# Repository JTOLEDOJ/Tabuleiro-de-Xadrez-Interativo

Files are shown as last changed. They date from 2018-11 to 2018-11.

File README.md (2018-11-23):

# TCIC

Nome do projeto: "Implementação de um sistema eletromecânico para auxílio de novos jogadores de xadrez utilizando a plataforma Arduino"

Autores:
* Álvaro Carvalho Vieira
* Erick de Barros Alcântara
* Igor Lima Rodrigues Pereira
* José Antonio Toledo Júnior

Universidade: UFSJ-CAP

Curso: Engenharia Mecatrônica

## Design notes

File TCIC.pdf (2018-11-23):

Universidade Federal de São João del-Rei

Campus Alto Paraopeba

## TRABALHO DE CONTEXTUALIZAÇÃO E INTEGRAÇÃO

## CURRICULAR – TCIC

“Implementação de um sistema eletromecânico para auxílio de novos

jogadores de xadrez utilizando a plataforma Arduino”

Álvaro Carvalho Vieira

Erick de Barros Alcântara

Igor Lima Rodrigues Pereira

José Antonio Toledo Júnior

Ouro Branco, MG

Julho de 2018

UNIVERSIDADE FEDERAL DE SÃO JOÃO DEL-REI

INSTITUIDA PELA LEI Nº. 10.425 DE 19/04/2002 – D.O.U DE 22/04/2002 CAMPUS ALTO PARAOPEBA
ENGENHARIA MECATRÔNICA

Álvaro Carvalho Vieira

Erick de Barros Alcântara

Igor Lima Rodrigues Pereira

José Antonio Toledo Júnior

“IMPLEMENTAÇÃO DE UM SISTEMA ELETROMECÂNICO PARA

AUXÍLO DE NOVOS JOGADORES DE XADREZ UTILIZANDO A

PLATAFORMA ARDUINO”

Trabalho apresentado ao Bacharelado

Interdisciplinar em Ciência e Tecnologia da

Universidade Federal de São João del-Rei

(UFSJ), como requisito essencial para

obtenção do grau de Bacharel, sob a

orientação do Prof. Dr. Guilherme Gomes

da Silva.

Ouro Branco, MG

Julho de 2018

AGRADECIMENTOS

É muito bom passar por uma jornada dessas, ter tanto a agradecer e querer

homenagear tantas pessoas. É muito valioso dizer obrigado a todos aqueles que,

durante este período, em que foi despertado sentimento de tristeza, incapacidade,

euforia, incerteza, cansaço, alegrias, conseguiram manter-se inevitavelmente

presentes. Por isso, as homenagens:

A Deus, Aquele que se apresentou e se apresenta nas mais variadas formas,

sendo este o motivo de continuar a tentar e almejar a conclusão de nossos sonhos,

dando-nos força para finalizar este projeto.

Em especial aos nossos pais, a quem devemos a vida, a formação moral e a

criação de nossa identidade. Nosso reconhecimento e gratidão por toda a paciência,

amor, compreensão e apoio constante.

Aos professores, os parabenizamos pelo compromisso e dedicação. Nossos

eternos agradecimentos pelas inúmeras contribuições.

Aos nossos queridos colegas e amigos, pelos momentos de convívio, risos,

trocas de conhecimentos, afetos e intrigas, e que por meio delas, amadurecemos.

RESUMO

O presente trabalho objetiva a elaboração de um tabuleiro de xadrez que auxilie

novos jogadores a aprenderem de forma interativa a jogar tal jogo. Para atingir a

finalidade proposta, foi utilizado software de simulação mecânica, plataforma Arduino,

fundamentos teóricos de programação, circuitos elétricos e eletrônica, além das leis

que regem o jogo. No desenvolver deste projeto, foi mostrado como hardware e

software, além da estrutura mecânica, foram elaborados para funcionarem em

conjunto, obtendo o resultado esperado do protótipo construído para facilitar

jogadores novatos de xadrez.

Palavras Chave: Projeto, Xadrez, Arduino.

ABSTRACT

The present work aims at the elaboration of a chessboard that helps new players

to learn the interactive way of playing the game. For the proposed adaptation, it was

used the software of accumulated mechanics, Arduino platform, theoretical

fundamentals of programming, electrical and electric, besides the laws that govern the

game. In the build this design, it was exposed how hardware and software, in addition

to the mechanical structure, were designed to work together, getting the expected

result of the prototype to be improved in novices of chess.

Keywords: Project, Chess, Arduino.

LISTA DE ILUSTRAÇÕES

LISTA DE SIGLAS

1. IMSA – Associação Internacional de Esportes Mentais | 11
2. FIDE – Federação Internacional de Xadrez | 13
3. USB – Universal Serial Bus | 18
4. PC – Personal Computer | 18
5. DC – Direct Current | 19
6. IOREF – Input/Output Reference | 20
7. GND – Ground | 20
8. VIN – Voltage Input | 21
9. CDC – Communication Device Class | 21
10.RISC – Reduced Instruction Set Computer | 21
11.TQFP – Quad Flat Package | 21
12.SMD – Surface Mount Tecnology | 21
13.SRAM – Static Random Access Memory | 21

14.EEPROM – Electrically-Erasable Programmable Read-Only Memory .........21

15.PWM – Pulse-Width Modulation | 22
16.RX – Data Reciver | 22
17.TX – Data Transmiter | 22
18.I2C – Inter-Integrated Circuit | 22
19.SDA – Serial Data | 22
20.SCL – Serial Clock | 22
21.SPI – Serial Peripheral Interface | 23
22.ICSP – In-circuit serial programming | 23
23.AD – Analog-to-Digital | 23
24.AD – Analog Reference | 23
25.LED – Light Emitting Diode | 23
26.DEMUX – Demultiplexer | 25
27.MUX – Multiplexer | 26
28.PCB – Printed Circuit Board | 27
29.CNC – Computer Numeric Control | 33
30.CD/DVD – Compact Disc / Digital Versatile Disc | 42

SUMÁRIO

### 1. INTRODUÇÃO

Ao contextualizar o termo automação, tem-se como foco e visão um sistema

automático de controle pelo qual os mecanismos verificam seu próprio funcionamento,

efetuando medições e introduzindo correções, sem a necessidade da interferência do

homem [1].

Em seu uso moderno, a automação pode ser definida como uma tecnologia que

utiliza comandos programados para operar um dado processo, combinados com

retroação de informação para determinar que os comandos sejam executados

corretamente. Frequentemente utilizada em processos antes operados por seres

humanos, é a aplicação de técnicas computadorizadas ou mecânicas para diminuir o

uso de mão-de-obra em qualquer processo [2].

Ao ingressar no curso de Engenharia Mecatrônica na Universidade Federal de

São João del-Rei - Campus Alto Paraopeba (UFSJ-CAP), são apresentados ao aluno

conhecimentos na área da automação, controle, eletrônica, programação e mecânica

durante aulas, palestras, seminários, viagens técnicas, feiras e outras atividades

complementares que possibilitam a formação de uma pessoa dinâmica, criativa, lógica

e resiliente.

Por meio deste processo o aluno está capacitado a procurar oportunidades de

projetos, conceber a ideia e desenvolvê-las por meio de uma Iniciação Científica, TCC,

TCIC ou Programa de Extensão. Tudo isso é estruturado por uma extensa pesquisa,

parte primordial para a implementação de qualquer projeto.

A popularização dos microcontroladores junto com a queda dos custos de

componentes eletrônicos, baterias e motores, possibilitaram o desenvolvimento de

pequenas plataformas autônomas de baixo custo [3].

A implementação de uma plataforma automática envolve conceitos de

eletrônica, computação e mecânica que, integrados de forma sincronizada,

possibilitam a construção de um sistema embarcado. Para realizar essa integração é

utilizado um microcontrolador que gerenciam os periféricos a ele conectados. Através

de embasamentos teóricos, ocorre a ideia de criar um “xadrez interativo”, com o objetivo de auxiliar novos jogadores no processo de aprendizado sobre o jogo,

tornando mais intuitivo e ágil esse processo.

### 2. REFERENCIAL TEÓRICO

### 2.1 Xadrez

O jogo de xadrez, integrado como esporte mental pela Associação Internacional

de Esportes Mentais (IMSA) desde 2005, é reconhecido por desenvolver as

capacidades de cognição como memória, tomada de decisão, raciocínio lógico-

matemático e inteligência espacial.

Segundo o papa Inocêncio III (papa entre 1198 e 1216) [4]:

Este mundo todo é como um tabuleiro de xadrez: uma casa é branca, outra casa é preta, e assim representa o duplo estado de vida ou de morte, de graça ou pecado. A família que habita esse tabuleiro é formada pelos homens deste mundo, que – tal como as peças saídas todas da mesma bolsa – procedem todos de um só ventre materno. E, tal como as peças, assumem seus postos nos diferentes lugares deste mundo, cada um com sua própria denominação. O primeiro é o Rei, depois a Rainha, em terceiro lugar a Torre, em quarto o Cavalo, em quinto o Bispo e em sexto o Peão. E o caráter do jogo é tal que um toma o outro e, com o jogo terminado, assim como todos tinham saído da mesma bolsa, a ela voltam. E então já não há diferença entre o Rei e o pobre Peão, pois acabam do mesmo modo o rico e o pobre. E com frequência acontece que, quando se devolvem as peças, o Rei fica por baixo, no fundo do saco; e assim também acontece com os grandes que ao sair deste mundo são sepultados no inferno; enquanto os pobres são levados ao seio de Abraão.

A referência [5] traz as informações a seguir, sendo que para eles o xadrez

apresenta-se como uma rica ferramenta no processo de tomada de decisões para os

diversos fatores de nossa vida. Diferentemente de outros esportes-jogos, como no

futebol onde o centroavante desperdiça vários chutes à gol – concluindo muitas vezes

apenas uma tentativa entre tantas – o xadrez com toda a sua precisão não permite

este “luxo”, pois qualquer que seja pequeno o erro de cálculo ou má visualização da

tomada de decisão, pode acarretar em uma derrota imediata, assim:

“As decisões são escolhas tomadas com base em propósitos, são ações

orientadas para determinado objetivo e o alcance deste objetivo determina a eficiência

do processo de tomada de decisão” (SHENK, 2006).

Xadrez é claramente um "caminho ideal para o estudo de tomada de decisão e

resolução de problemas, porque é um sistema fechado, com regras claramente

definidas" (Horgan, 1988).

Quando confrontados com um problema, o primeiro passo é "analisar [o] de

uma forma preliminar e impressionista: avaliando o problema" (Horgan, 1988, p. 3),

possivelmente à procura de padrões ou semelhança com experiências anteriores.

"Juízos de similaridade pode envolver altos níveis de raciocínio abstrato" (Horgan,

1988, p. 3). Como o estudo de padrões na matemática, o reconhecimento de padrões

em xadrez é de primordial importância na resolução de problemas. Depois de

reconhecer a semelhança de padrões, uma estratégia global pode ser desenvolvida

para resolver o problema. Trata-se de alternativas de produção, um processo criativo.

Um bom jogador de xadrez, como um solucionador de problemas bom, tem

"adquirido um vasto número de esquemas inter-relacionados" (Horgan, 1988, p. 3),

permitindo uma boa alternativa para rápida e fácil resolução vêm à mente. Essas

alternativas devem ser avaliadas, através de um processo de cálculo conhecido como

análise da árvore de decisão, onde solver o jogador de xadrez / problema é calcular a

conveniência de eventos futuros com base nas alternativas estão sendo analisadas.

Horgan (1988) constatou que "o cálculo pode ir várias jogadas a oito ou dez

anos à frente. Esta fase exige concentração grave e habilidades de memória ... [ou]

... imagética visual" (p.4).

Depois que uma alternativa adequada para resolver o problema é alcançada e

implementada, ela pode ser avaliada. Os jogadores de xadrez, como todos os bons

solucionadores de problemas, voltam e avaliam o resultado de uma solução para

aumentar o seu nível de especialização. "Peritos e especialistas em potencial quer

saber, mesmo quando eles forem bem-sucedidos, se houvesse uma alternativa

melhor à sua disposição" (Horgan 1988, p.6). Segundo Bloom (1956), este processo

de avaliação é um dos objetivos mais importantes da aprendizagem e deve, portanto,

ser considerado um dos maiores objetivos educacionais de nossas escolas. "A

tendência do xadrez para desenvolver habilidades que podem ser usadas para lidar

com as complexidades da vida o tornam uma ferramenta valiosa para o aprendizado.

Xadrez deve ser uma disciplina optativa no currículo das escolas públicas" (Schmidt,

p. 6).

### 2.1.1 Natureza e objetivos do jogo de xadrez

Segundo as leis da Federação Internacional de Xadrez (FIDE 2009), o jogo de

xadrez é disputado entre dois oponentes que movem peças alternadamente sobre um

tabuleiro quadrado denominado tabuleiro de xadrez. O jogador com as peças brancas

começa o jogo. Diz-se que um jogador “tem a vez de jogar” quando a jogada do seu

oponente tiver sido feita.

O objetivo de cada jogador é colocar o rei do oponente sob ataque de tal forma

que o oponente não tenha lance legal. O jogador que alcançar esse objetivo diz-se

que deu “xeque-mate” no rei do adversário e venceu a partida. Não é permitido deixar

ou colocar o seu próprio rei sob ataque, bem como capturar o rei do oponente.

O oponente cujo rei sofreu xeque-mate perdeu a partida. A partida está

empatada se resultar numa posição em que nenhum dos jogadores tem possibilidade

de dar xeque-mate [6].

### 2.1.2 Posição inicial das peças no tabuleiro

No início da partida, um jogador tem 16 peças de cores brancas e o outro tem

16 peças de cores pretas, sendo o tipo e quantidade de cada peça demonstrados na

Figura 1.

O tabuleiro de xadrez é composto de uma rede de 8x8 com 64 casas iguais,

alternadamente entre claras (brancas) e escuras (pretas), como mostrado na Figura

2. O tabuleiro é colocado entre os jogadores de tal forma que seja branca a casa do

canto à direita de cada jogador.

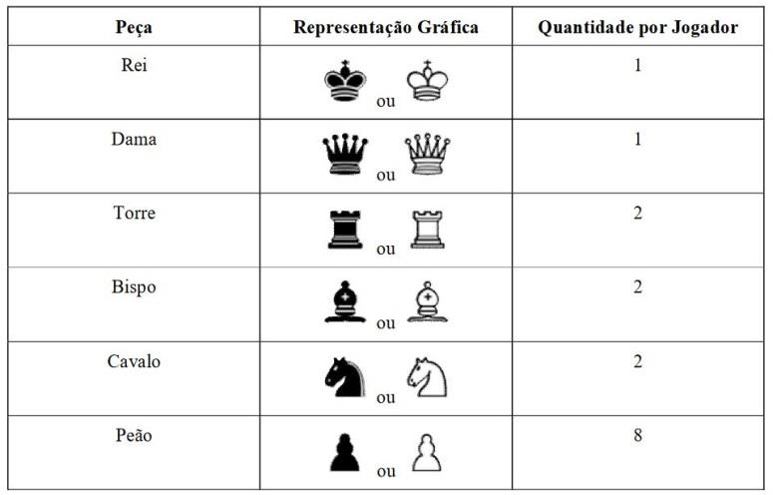
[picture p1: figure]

Figura 1 - Tipos de peças do xadrez [6]

Figura 2 - Posição inicial das peças de xadrez no tabuleiro [6]

As oito casas dispostas verticalmente são chamadas de colunas. As oito casas

dispostas horizontalmente são chamadas de fileiras. A linha reta de casas da mesma

cor, movendo-se de uma ponta do tabuleiro a uma ponta adjacente, é chamada de

diagonal [6].

### 2.1.3 Movimento das peças

Não é permitido mover uma peça para uma casa já ocupada por outra peça de

mesma cor. Se uma peça for movida para uma casa já ocupada por uma peça do

oponente, esta última é capturada e retirada do tabuleiro como parte do mesmo

movimento. Diz-se que uma peça está atacando uma peça do oponente se puder

efetuar uma captura naquela casa.

Considera-se que uma peça ataca uma casa, mesmo se tal peça está impedida

de ser movida para esta casa, porque, consequentemente, deixaria ou colocaria o seu

próprio rei sob ataque.

O bispo pode mover-se para qualquer casa ao longo da diagonal em que se

encontra, como mostrado na Figura 3.

Figura 3 - Possíveis movimentos do bispo [6]

A torre se movimenta para frente e para trás, para a direita e para a esquerda,

quantas casas quiser, como mostrado na Figura 4.

Figura 4 - Possíveis movimentos da torre [6]

A dama pode mover-se para qualquer casa ao longo da coluna, fileira ou

diagonal em que se encontra, como mostrado na Figura 5.

Figura 5 - Possíveis movimentos da rainha [6]

Ao fazer esses movimentos, o bispo, torre ou dama não podem pular sobre

qualquer peça que esteja em seu caminho.

O cavalo pode ser movido para uma das casas mais próxima em relação à qual

ocupa, como mostrado na Figura 6. Note que a casa para a qual o cavalo pode mover-

se não está na mesma coluna, fileira ou diagonal.

Figura 6 - Possíveis movimentos do cavalo [6]

O peão pode ser movido para uma casa, imediatamente à sua frente, na mesma

coluna, que não se encontre ocupada, ou em seu primeiro lance o peão pode ser

movido conforme mencionado; alternativamente pode avançar duas casas ao longo

da mesma coluna, desde que ambas estejam desocupados, ou o peão pode ser

movido para uma casa ocupada por uma peça do oponente, que esteja diagonalmente à sua frente, numa coluna adjacente, capturando aquela peça. É possível perceber

tais movimentações na Figura 7.

Figura 7 - Possíveis movimentos do peão [6]

Um peão atacando uma casa atravessada pelo peão do oponente que acaba

de avançar duas casas num único lance vindo de sua casa original, pode capturar

este peão oponente como se aquele tivesse se movido apenas uma casa. Esta

captura pode ser feita apenas no movimento imediatamente após o referido avanço e

é chamada de tomada ‘en passant’.

Há duas formas diferentes de mover o rei: movendo-se o rei para qualquer casa

vizinha não atacada por uma ou mais peças do oponente ou ‘rocando’. Este é um

lance efetuado com o rei e uma das torres, de mesma cor ao longo da primeira fileira

do jogador, considerado como um único lance de rei e executado da seguinte forma:

o rei é transferido de sua casa original a duas casas em direção à torre que está em

sua casa original, em seguida a torre é transferida para a casa a que o rei acabou de

atravessar [6]. O movimento possível do rei está apresentado na Figura 8.

Figura 8 - Possíveis movimentos do rei [6]

### 2.2 Arduino

A plataforma aberta Arduino [7] possui interface intuitiva, preço acessível e é

utilizada bastante para testes ou fins educacionais. O Arduino Leonardo faz parte do

portfólio de placas disponíveis no mercado. Ele difere de placas Arduino anteriores,

pois possui um microcontrolador ATMEL de 8-bits com o periférico USB, o que elimina

o uso de um segundo microcontrolador com USB para programação. Além disso, essa

USB pode ser usada para controle pelo PC [8].

### 2.2.1 Alimentação

O Arduino Leonardo, assim como o Arduino UNO, pode ser alimentado tanto

pelo USB quanto por uma fonte externa, mostrada na Figura 9.

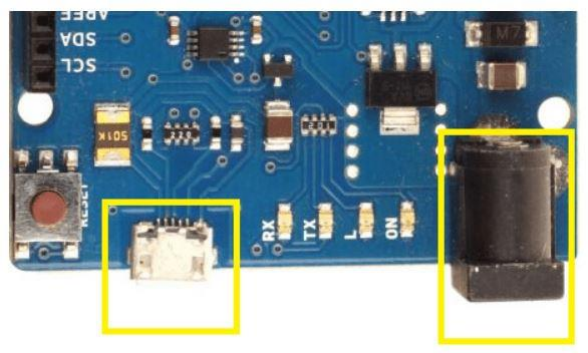
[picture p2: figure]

Figura 9 - Alimentação da placa Arduino Leonardo [8]

Como no Arduino UNO, a alimentação externa é feita através do conector Jack

com positivo no centro, onde o valor de tensão da fonte externa deve estar entre 6V e

20V. Se alimentada com uma tensão abaixo de 7V para o UNO e abaixo de 5V para

o Leonardo, que são suas respectivas tensões de funcionamento da placa, pode haver

instabilidade e quando alimentada com tensão acima de 12V, o regulador de tensão

da placa pode sobreaquecê-la e danificá-la.

O circuito regulador para entrada externa é exibido na Figura 10.

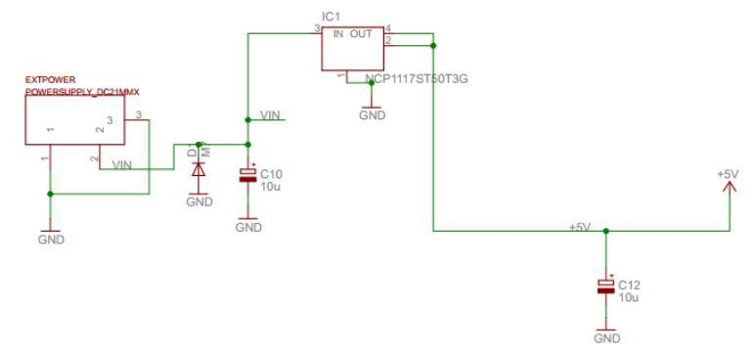
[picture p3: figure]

Figura 10 - Circuito regulador para entrada externa [8]

Quando o Arduino Leonardo é alimentado pela USB, a tensão da porta USB

não precisa ser estabilizada pelo regulador de tensão. Dessa forma a placa é

alimentada diretamente pelo USB. O circuito do USB exibido na Figura 11 apresenta

alguns componentes que protegem a porta USB do computador em caso de alguma

anormalidade.

Figura 11 - Circuito de proteção da USB da placa Arduino Leonardo [8]

O Arduino Leonardo possui o circuito mostrado na Figura 12 para seleção da

fonte de alimentação e alterna automaticamente entre a tensão do USB e a tensão da

fonte externa. Caso haja uma tensão no conector DC e o USB é conectado, a tensão

de 5V será proveniente da fonte externa e USB servirá apenas para comunicação com

o computador.

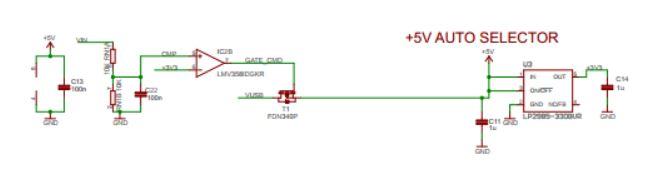
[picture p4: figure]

Figura 12 - Circuito de seleção de fonte [8]

Na Figura 13 são exibidos os conectores de alimentação para conexão de

shields e módulos na placa Arduino Leonardo [8].

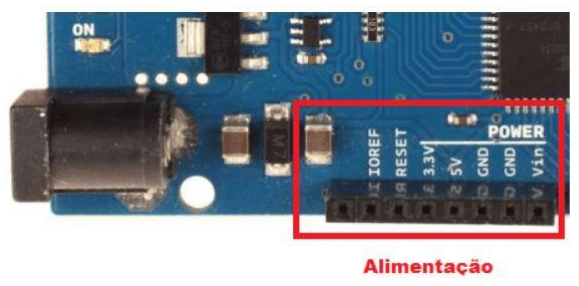
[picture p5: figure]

Figura 13 - Conectores de alimentação [8]

IOREF – Fornece uma tensão de referência para que shields possam

selecionar o tipo de interface apropriada. Dessa forma shields que funcionam com as

placas Arduino que são alimentadas com 3,3V podem se adaptar para ser utilizados

em 5V e vice-versa.

RESET – Pino conectado a pino de RESET do microcontrolador. Pode ser

utilizado para um reset externo da placa Arduino.

3,3V – Fornece tensão de 3,3V para alimentação de shields e módulos

externos. Corrente máxima de 50mA.

5V – Fornece tensão de 5V para alimentação de shields e circuitos externos.

GND – Pinos de referência, terra.

VIN – Pino para alimentar a placa através de shield ou bateria externa. Quando

a placa é alimentada através do conector Jack, a tensão da fonte estará nesse pino.

### 2.2.2 Comunicação USB

A placa Arduino Leonardo não possui circuito para interface USB, como o

Arduino Uno. A comunicação USB é feita pelo mesmo microcontrolador que executa

o sketch compilado. O microcontrolador Atmega32U4, que é o protagonista dessa

placa, possui comunicação USB integrada, assim não há a necessidade de um

conversor USB serial, como ocorre em outras placas Arduino. Este recurso reduz o

custo da placa. O USB pode operar como CDC device. Isso permite emular um

teclado, mouse, joystick ou qualquer dispositivo CDC padrão de mercado. O device

USB dele é 2.0, ou seja, pode atingir velocidade de comunicação de até 12MB/s [8].

### 2.2.3 Microcontrolador

O microcontrolador utilizado no Arduino Leonardo é o ATmega32U4,

apresentado na Figura 14, de 8 bits da família AVR com arquitetura RISC avançada.

Possui encapsulamento TQFP que apenas permite a montagem em superfície, ou

seja, é um componente SMD. Possui 32KB de memória Flash (porém utiliza 4KB para

o bootloader), 2,5KB de SRAM e 1KB de EEPROM [8].

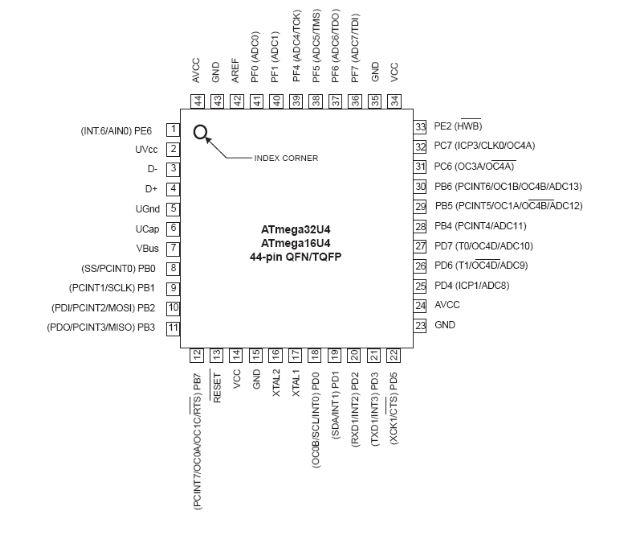
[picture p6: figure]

Figura 14 - Microcontrolador ATmega32U4 [8]

### 2.2.4 Pinos de entrada e saída

A placa Arduino Leonardo possui pinos de entradas e saídas digitais, assim

como pinos para saída PWM e pinos para entradas analógicas. Possui pinagem no

padrão REV3, conforme exibido na Figura 15.

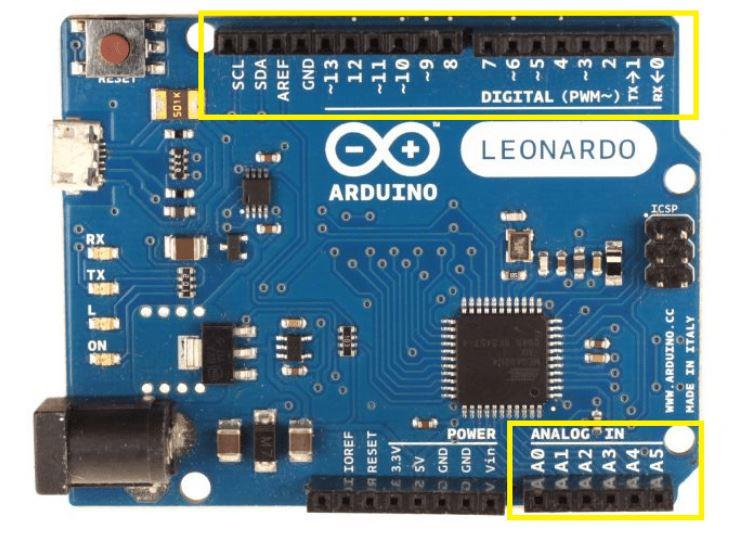
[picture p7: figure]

Figura 15 - Pinos de entrada/saída [8]

Todos os pinos podem ser usados como entradas ou saídas digitais, inclusive

os que estão dispostos para entradas analógicas. Estes pinos operam em 5V, onde

cada pino pode fornecer ou receber uma corrente máxima de 40mA. Cada pino possui

resistor de pull-up interno que pode ser habilitado por software. Esse resistor tem o

valor entre 20 e 50KΩ [8].

Comunicação Serial – pinos 0 (RX) e 1 (TX). Esses pinos são usados para enviar e receber dados através de comunicação serial. É interessante notar que para

usar esses pinos deve-se usar a classe Serial1, pois a classe Serial refere-se à

comunicação USB (CDC).

Comunicação TWI (I2C) – pinos 2 (SDA) e 3 (SCL). Permitem a comunicação

TWI (I2C da Atmel) usando a biblioteca Wire.

Interrupção externa – pinos 3 (interrupt 0), 2 (interrupt 1), 0 (interrupt 2), 1

(interrupt 3) e 7 (interrupt 4). Esses pinos podem ser configurados para disparar uma

interrupção quando ocorrer uma mudança no estado, uma borda de descida ou

subida, ou um nível baixo. Para mais detalhes verifique a função attachInterrupt().

Saídas PWM – pinos 3, 5, 6, 9, 10, 11 e 13. Podem ser utilizados como saídas

PWM de 8 bits de resolução através da função analogWrite().

Comunicação SPI – apenas está disponível no conector ICSP e pode ser

utilizado com a biblioteca SPI.

Entradas Analógicas – para interfacear com o mundo analógico, a Arduino

Leonardo possui 12 entradas analógicas. As entradas conhecidas para esse propósito

são A0-A5, além de mais 6 entradas que estão no lado dos pinos digitais, que são

denominadas A6 a A11 e estão respectivamente nos pinos digitais 4, 6, 8, 9, 10 e 12.

O conversor AD do ATmega32U4 possui resolução de 10 bits e sua referência está

ligada internamente a 5V, ou seja, quando a entrada estiver com 5V o valor da

conversão analógica digital será 1023. O valor da referência pode ser mudado através

do pino AREF.

### 3. OBJETIVOS

O principal objetivo desse projeto é a elaboração de um tabuleiro de xadrez que

seja capaz de mapear o jogo via software e indicar fisicamente através de luzes no

próprio tabuleiro quais posições a peça que se deseja mover poderá assumir. O

projeto em questão tem como objetivos específicos:

I. Utilizar uma interface que permita ao usuário entrar com a posição da peça que

se deseja mover;

II. Implementar um circuito eletrônico que possibilite acender qualquer um dos 64

LEDs do tabuleiro, a fim de mostrar ao usuário onde o mesmo pode mover a

peça. Este circuito será denominado de “circuito de escrita”;

III. Desenvolver uma lógica computacional para analisar as jogadas, recebendo a

posição da peça que se deseja mover e acendendo os LEDs corretos para

aquela jogada do usuário.

Como possível extensão do projeto, tentar-se-á elaborar um circuito que

identifique automaticamente qual peça será movida simplesmente levantando-a do

tabuleiro, eliminando assim a necessidade de indicar via software qual será a peça.

Este circuito será denominado de “circuito de leitura”.

### 4. MÉTODOS E RESULTADOS

Para uma melhor explicação, o conteúdo desta seção foi dividido em 3

subseções (Mecânica, Programação e Eletrônica) intimamente relacionadas, porém

individualmente explicadas.

### 4.1 Mecânica

Pensando na maior interatividade possível entre homem e equipamento,

primeiramente implementou-se no SolidWorks [9] um projeto mecânico que auxiliasse

os alunos na concepção do mesmo, tornando assim mais palpável e de fácil

visualização de possíveis desafios durante montagem.

Foram utilizadas 3 placas de madeira 300x300x6mm de dimensão. A placa

mais em baixo representada na Figura 16 será denominada “base”, enquanto do

centro representada na Figura 17 será nomeada “superfície 2” e, por fim, a superior

representada na Figura 18 será chamada de “superfície 1”. A base comporta o Arduino

e as placas eletrônicas, ficando distante das superfícies, que contêm o encaixe dos

LEDs, peças e contatos.

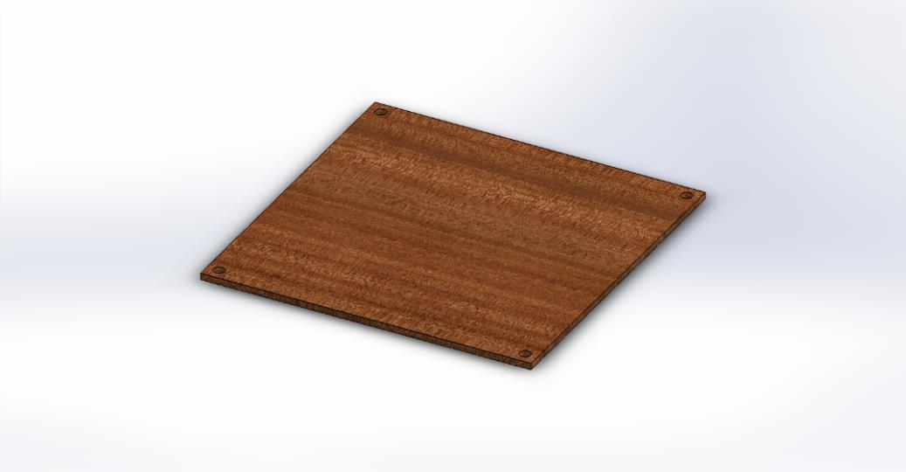
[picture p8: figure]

Figura 16 - Desenho isométrico da base

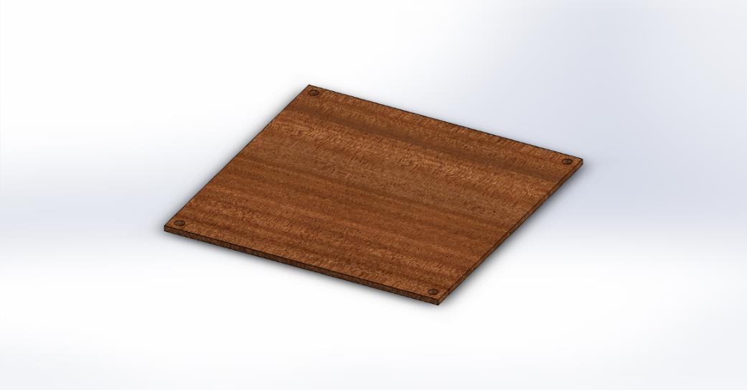
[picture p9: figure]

Figura 17 - Desenho isométrico da superfície 2

Figura 18 - Desenho isométrico da superfície 1

A fim dos circuitos e dos fios ficarem no meio da base e das superfícies

permitindo fácil manuseio dos mesmos, um sistema de fixação composto por 4 barras

roscadas de 150mm de altura e 3/8” de diâmetro, 16 porcas sextavadas e 16 arruelas

foi utilizado, apresentados na Figura 19, Figura 20 e Figura 21, respectivamente. Para

uma boa fixação mecânica, passou-se para cada furo de sustentação uma arruela na

parte de dentro e na parte externa na chapa de madeira e o fechamento deu-se

através de duas porcas.

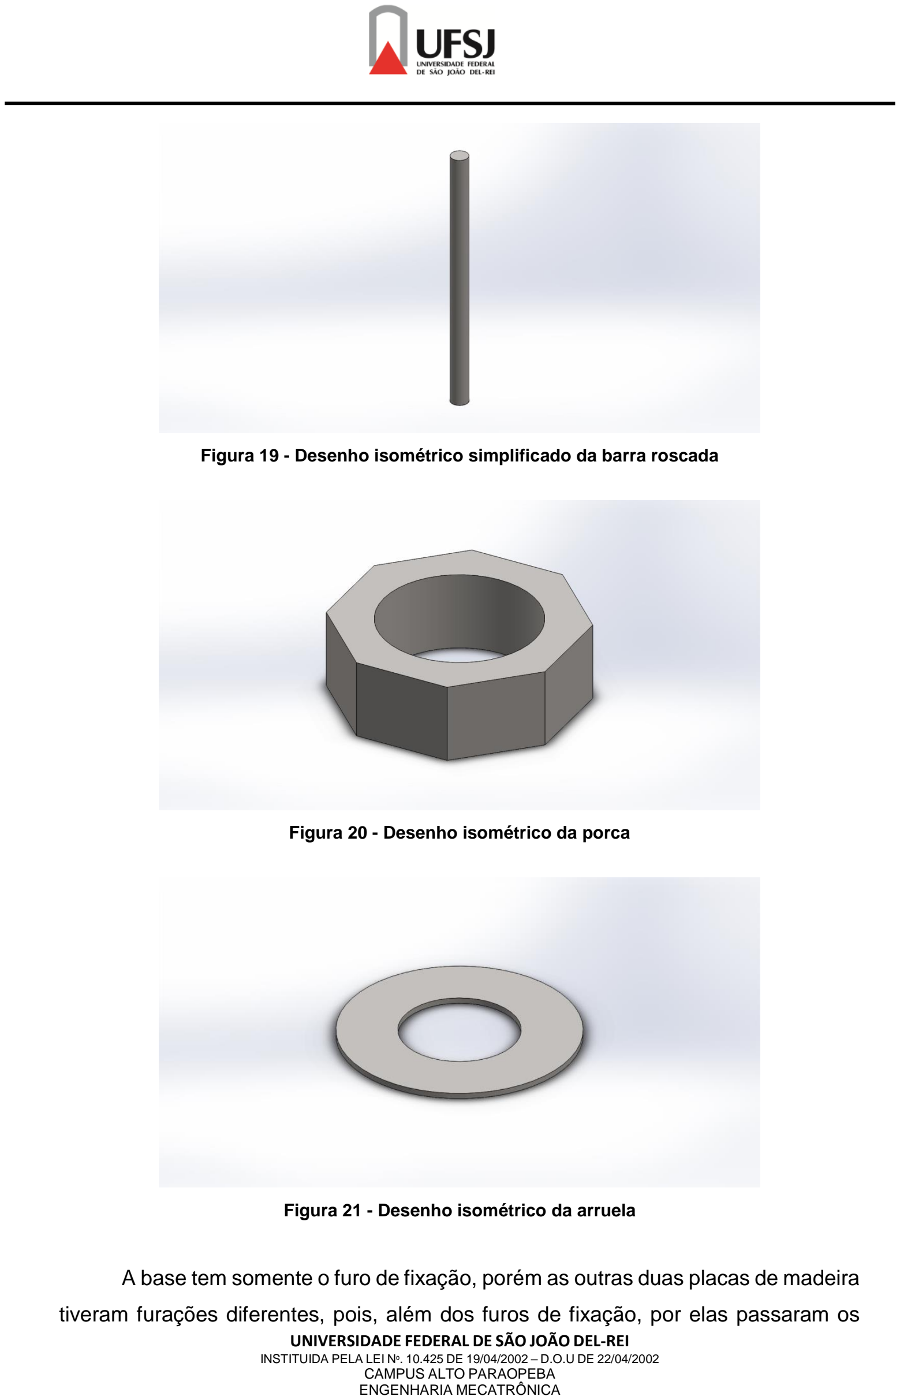
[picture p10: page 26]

Figura 19 - Desenho isométrico simplificado da barra roscada

Figura 20 - Desenho isométrico da porca

Figura 21 - Desenho isométrico da arruela

A base tem somente o furo de fixação, porém as outras duas placas de madeira

tiveram furações diferentes, pois, além dos furos de fixação, por elas passaram os

LEDs, os contatos e os furos maiores, necessário para encaixar as peças. Um

desenho simplificado de LED está exibido na Figura 22.

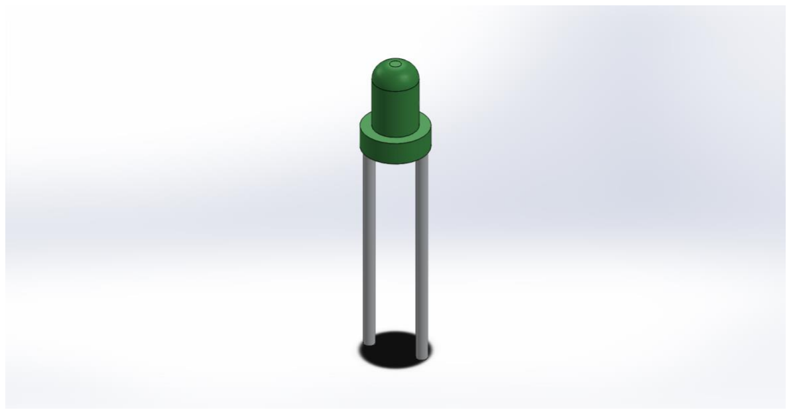
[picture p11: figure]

Figura 22 - Desenho isométrico do LED

Em específico a superfície 1 apresenta os furos de encaixe das peças e dos

LEDs, já a superfície 2 possui os furos dos contatos e também dos LEDs. Essa

“camada” superficial foi dividida em duas placas devido a facilidade do CNC em

perfurar por completo uma das placas de 6mm ao invés de perfurar e remover um

cilindro de 6mm de altura e 25mm de diâmetro numa chapa de 12mm inteiriça.

Os furos dos LEDs e contatos foram feitos na CNC com broca de diâmetro

2mm, mas a espessura do fio é de aproximadamente 0,5mm, o que proporcionou uma

folga para fácil movimentação, caso fosse necessário. Como a superfície 2 contém

apenas furos muito pequenos, exceto os de sustentação, a imagem da Figura 17

assemelha-se muito com a base mostrada na Figura 16, porém se for dado o zoom é

possível ver que a base não contém os furos de 2mm que a superfície 2 contém.

Os contatos foram feitos através de fios, devido ao seu baixo custo, fácil

manuseio e montagem facilitada quando comparados ao uso de pequenas chapas

metálicas, a qual deveria ser cortada e soldada aos fios da placa de escrita, o que

demandaria mais trabalho e mais gastos financeiros. Um exemplo de par de contatos

está mostrado na Figura 23. Antes da montagem física passou-se papel alumínio nos

fios para que obtivesse uma maior área de contato.

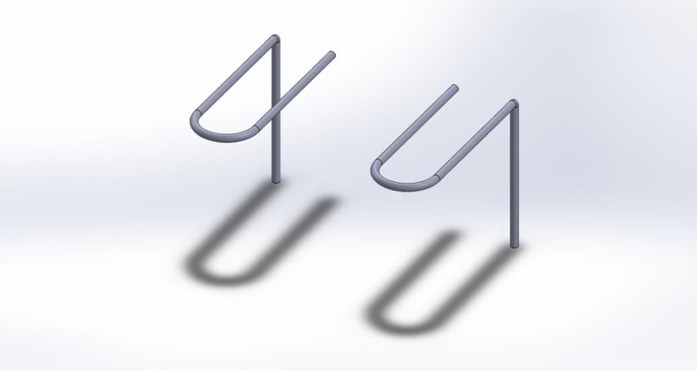
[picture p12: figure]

Figura 23 - Desenho isométrico dos contatos

Uma solução de melhor implementação e mais alta confiabilidade seria o uso

de Reed Switchs ou sensores de fim de curso, porém como seriam 64 componentes

desses, o valor do projeto sairia do previsto, descartando assim essa opção.

### 4.1.1 Desenho das peças

As peças do tabuleiro de xadrez foram retiradas de um projeto Open Source da

internet [10], sendo necessário apenas a adaptação das medidas de cada peça para

adequação ao projeto. As peças apresentadas são da cor preta, porém há também as

de cor branca que não foram exibidas isoladamente aqui.

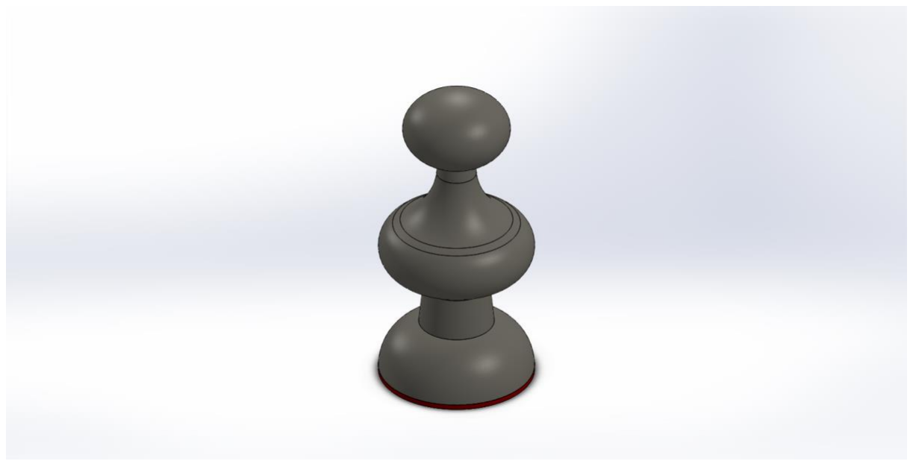
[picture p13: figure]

Figura 24 - Desenho isométrico do peão [10]

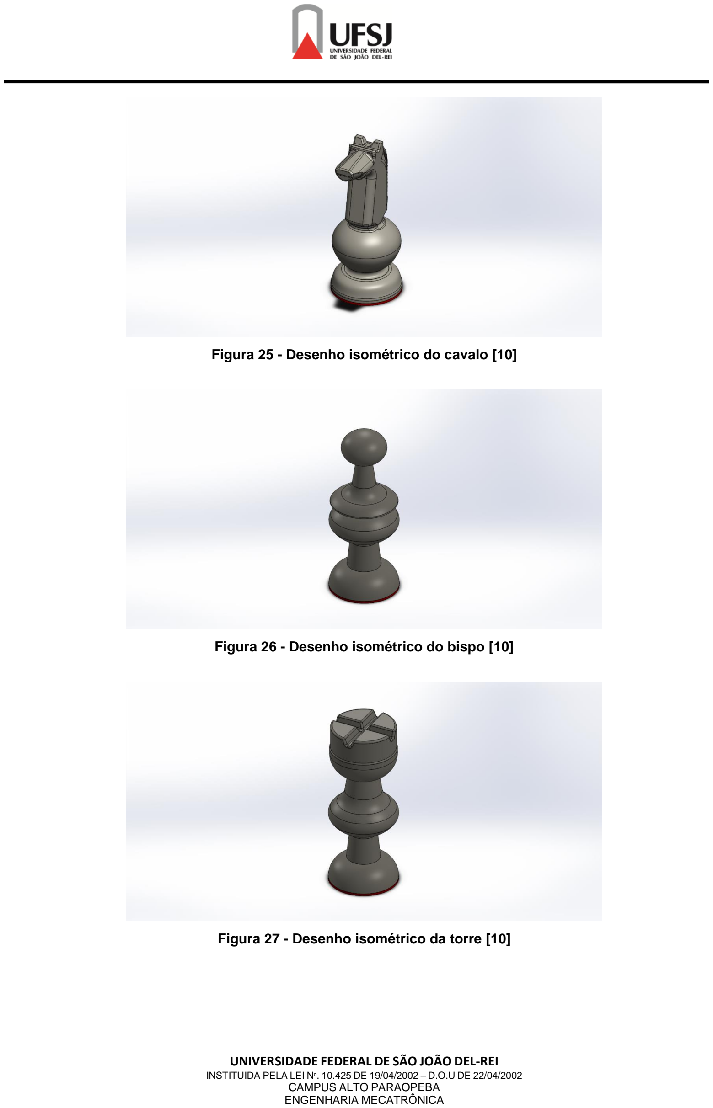
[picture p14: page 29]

Figura 25 - Desenho isométrico do cavalo [10]

Figura 26 - Desenho isométrico do bispo [10]

Figura 27 - Desenho isométrico da torre [10]

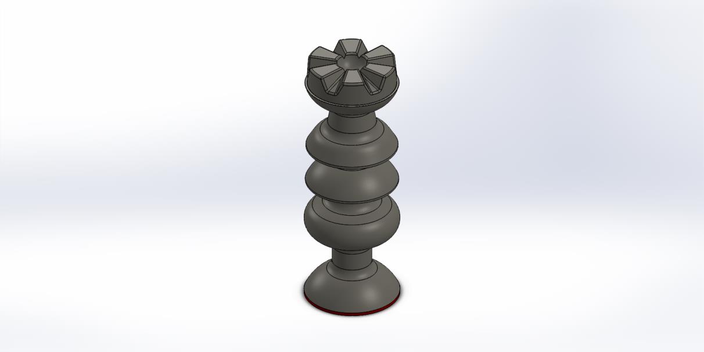
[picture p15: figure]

Figura 28 - Desenho isométrico da rainha [10]

Figura 29 - Desenho isométrico do rei [10]

### 4.1.2 Resultado da montagem no software

Antes da obtenção da montagem final, colou-se 2 arruelas na base de cada

peça do tabuleiro para dar mais aderência e peso, a fim de melhorar o contato com o

papel alumínio – foi necessário lixar o lado de contato da arruela com o papel alumínio.

Um papel xadrez foi adicionado à montagem para a estética do projeto. Este

papel e o resultado da montagem no SolidWorks podem ser conferidos na Figura 30

e Figura 31, respectivamente.

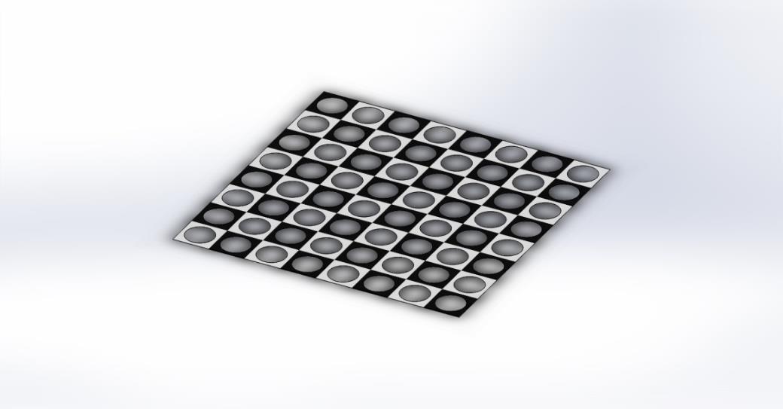
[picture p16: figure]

Figura 30 - Desenho isométrico do acabamento xadrez de papel

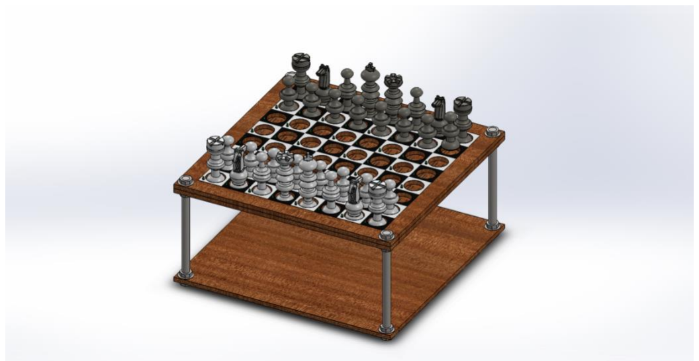
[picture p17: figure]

Figura 31 - Desenho isométrico da montagem do tabuleiro

### 4.2 Programação

O código disponível na referência [11] foi criado na plataforma Arduino e

permite controlar os pinos do microcontrolador utilizado a fim de acender os LEDs nas

posições corretas para todas as peças e situações do jogo.

A linguagem de programação do Arduino é considerada de alto nível e é

baseada em C++, com algumas pequenas modificações. Dessa forma, a maioria das

funcionalidades e estruturas já são amplamente conhecidas e difundidas na

comunidade.

Há duas funções padrões no Arduino: void setup() e void loop(). A primeira é

executada apenas na inicialização do sistema e normalmente define parâmetros e pinos a serem utilizadas durante o código. A segunda função é executada

continuamente até o interrompimento do programa, sendo responsável pela execução

propriamente dita de todo o sistema.

O tabuleiro de xadrez foi mapeado em uma matriz de inteiros, de tamanho 8x8,

dentro da função void Inicio(), chamada pela void setup(). Cada peça tem sua

numeração associada: Peão (1), Torre (2), Bispo (3), Cavalo (4), Rainha (5) e Rei (6).

No caso de peças brancas a numeração é positiva (+) e peças pretas é negativa (-),

além de posições sem peça serem zero (0).

Inicialmente o jogador seleciona através do terminal serial do Arduino,

mostrado na Figura 32 uma peça a ser movida, indicando para isso a linha (letra ‘a’

até ‘h’) e uma coluna (número ‘1’ a ‘8’). A função void Leitura() realiza a tarefa de pegar

e verificar tais entradas passadas ao programa e prepará-las para as próximas etapas

do código, utilizando também como auxílio as funções void TrocaLinha() e void

TrocaColuna().

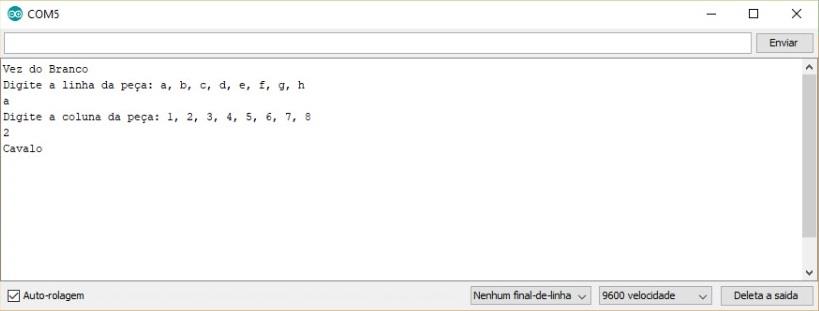
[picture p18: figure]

Figura 32 - Porta serial do Arduino

Após selecionar a peça a ser movida, o programa utiliza a função void

Movimenta() para acender as posições que a peça escolhida pode assumir. Para cada

peça há uma parte individual do código que trata a sua movimentação e sua

possibilidade de capturar peças adversárias. Foi importante separar o código dessa

forma, pois cada peça exige uma movimentação e captura distinta das demais.

Para acender um LED deve-se passar para a função void AcendeLed (int linha,

int coluna) a linha e coluna que se deseja acender. Essa função chama outras duas

funções, void SelectDemuxLinha (int s) e void SelectDemuxColuna (int s), que

recebem a linha e coluna, respectivamente, através de um inteiro que varia de 0 a 7.

Assim as duas funções selecionam os selects do respectivo DEMUX convertendo este

número inteiro em 3 bits, acendendo tal posição.

Quando o jogador decidir para qual casa ele irá mover, o mesmo deve inserir

no serial do Arduino a linha e a coluna da posição desejada, da mesma forma que o

fez quando selecionou a peça a ser movida. Assim como a função void Leitura(), quem

realiza tais ações neste caso é a função void Leitura2().

Após um jogador realizar a sua vez de jogar, o programa realiza as mesmas

operações para o adversário, até que um dos dois vença o jogo. Toda a parte de

comunicação com os jogadores é realizada através do terminal serial do Arduino,

sendo que o programa trata eventos não corretos que o jogador possa realizar, como:

capturar a própria peça, tentar inserir uma posição inválida para a movimentação ou

ainda tentar selecionar uma peça para movimentá-la sendo que a posição não contém

nenhuma peça.

### 4.3 Eletrônica

Utilizando a interface que seleciona a peça a ser movida, fica necessário

apenas criar um circuito eletrônico que acenda os LEDs desejados (circuito de

escrita). Porém, como tentativa de deixar o jogo mais automático e direto, ou seja,

sem a necessidade de um computador executando tal interface com o usuário, foi

trabalhado outro circuito eletrônico que identificasse as peças do tabuleiro a cada

jogada (circuito de leitura).

### 4.3.1 Circuito de escrita

Para acender um LED basta alimentar a sua extremidade positiva (ânodo) com

3,3V e sua extremidade negativa (cátodo) com 0V. A fim de utilizar apenas as

alimentações de 5V do Arduino, se faz necessário colocar uma resistência entre a

alimentação do Arduino e o ânodo do LED, sendo o valor de 330Ω escolhido para este caso. Para acender os 64 LEDs foram utilizados dois DEMUX TC4053BP, um jogando

5V em uma das 8 saídas e outro jogando 0V também em uma das saídas, como

mostrado na Figura 33.

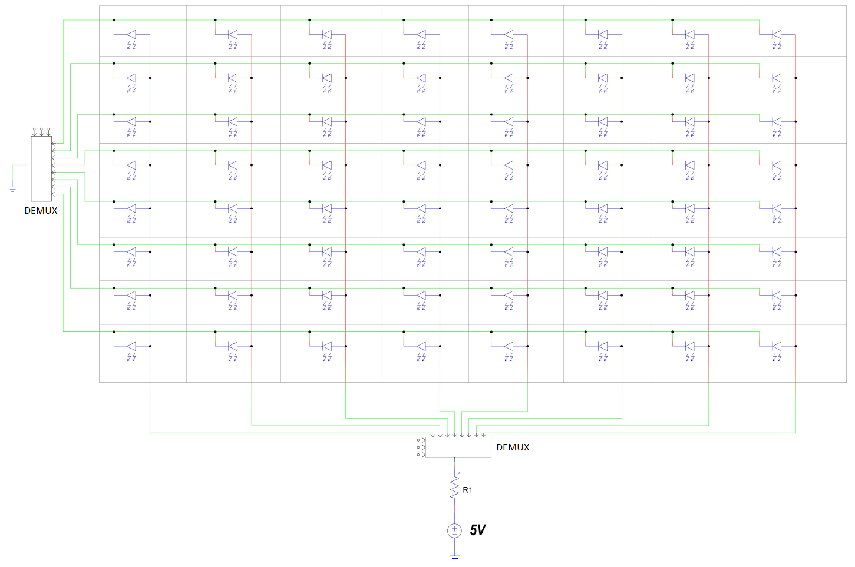
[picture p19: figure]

Figura 33 - Representação do circuito de escrita

Para a elaboração do circuito físico, o circuito de escrita também foi dividido em

2 sub-circuitos com 1 DEMUX cada, sendo diferenciados apenas pelo valor de tensão

que eles jogam em suas saídas. Foram elaborados os PCBs apresentados na Figura

34 e Figura 35 no software Proteus [12].

Selecionando os selects dos DEMUXs é possível escolher qual linha e qual

coluna, ou seja, uma posição específica, para acender o LED. Exemplificando uma

situação, quando o DEMUX lança 5V na coluna 1, o outro DEMUX lança 0V em

qualquer uma das linhas, por exemplo na linha 3, assim o LED dessa posição recebe

0V na sua perna negativa e 3,3V na sua perna positiva, ascendendo.

Através do código, após a peça ser retirada do contato, o programa comandava

os dois DEMUX para que eles fizessem um cruzamento de malhas e conseguissem acionar os LEDs certos, mostrando as possíveis jogadas daquela peça. Porém, como

o circuito pode apenas acender um LED por vez, foi necessário pensar numa

estratégia consistente que fizesse parecer que mais de um LED estava aceso ao

mesmo tempo.

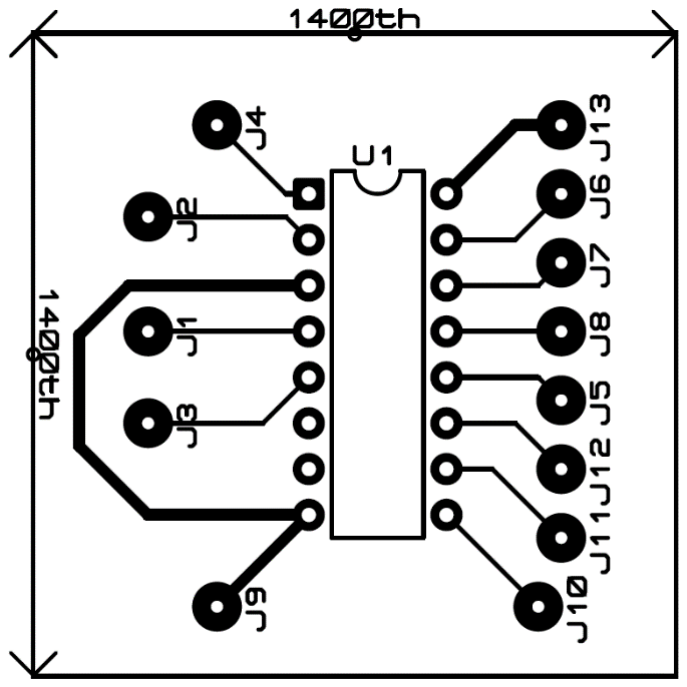
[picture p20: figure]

Figura 34 - Sub-circuito com DEMUX para o cátodo do circuito de escrita

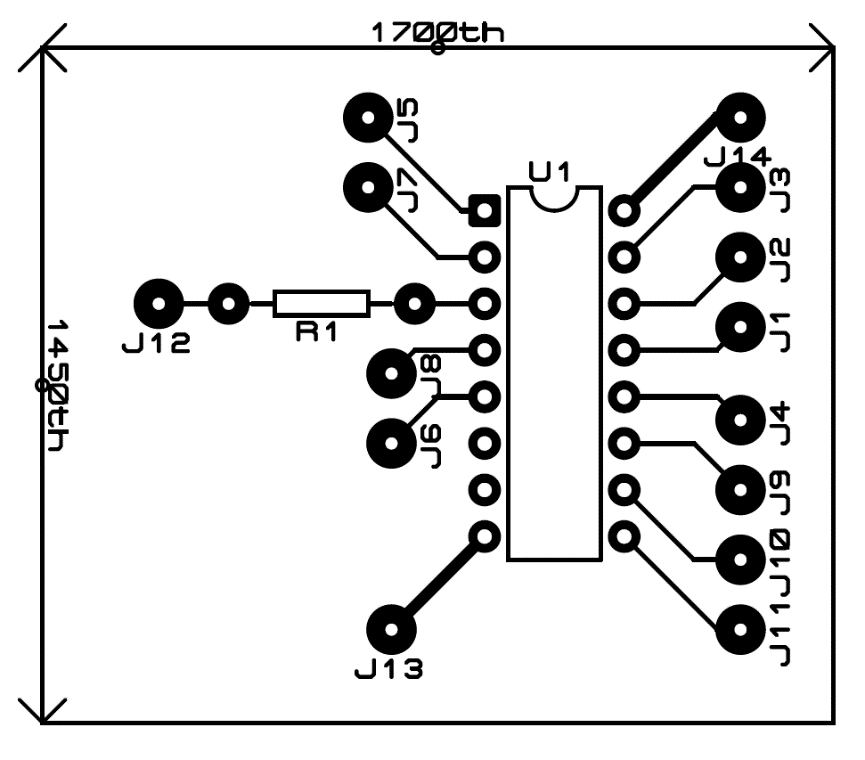
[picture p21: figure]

Figura 35 - Sub-circuito com DEMUX para o ânodo do circuito de escrita

O olho humano consegue identificar diferenças em vídeos abaixo de 30

quadros/segundo aproximadamente. Assim, se for projetado para um mesmo LED

piscar acima dessa frequência, aparentemente ele ficaria acesso. Logo, se os DEMUX

selecionassem o LED 1 (primeira coluna e primeira linha) e o acendesse, percorresse todas as outras 63 posições rapidamente e acendesse o primeiro LED de novo, acima

da frequência que o olho humano consegue perceber essa diferença, aparentemente

não seria notado que ele piscou. Essa foi a grande ideia – simples, porém poderosa –

para contornar o problema de deixar duas ou mais posições acessas ao mesmo tempo

no tabuleiro.

Dessa forma, todas as 3 partes essenciais do projeto (montagem mecânica,

programação e circuito de escrita) foram descritas individualmente e unidas para fazer

o protótipo atender ao propósito que foi construído. Até aqui é necessário que os

usuários utilizem a porta serial do Arduino através de um computador com a

plataforma Arduino para inserir as posições, logo deixa o jogo não dinâmico e acaba

necessitando de alguém que saiba utilizar tal funcionalidade do Arduino. Dessa forma

tentou-se elaborar um circuito de extensão desse projeto que eliminasse o

computador para interfaceamento com o jogador e deixasse a identificação das peças

totalmente automática, sendo apresentado na seção 4.3.2.

### 4.3.2 Circuito de leitura

O grande desafio para o circuito de leitura foi pensar em como o software iria

identificar a presença de peça numa determinada posição. Cogitou-se a utilização de

sensores indutivos, piezoelétricos e reed switchs próximos às peças, porém qualquer

uma dessas soluções iria encarecer consideravelmente o projeto.

Uma última solução, mais barata, porém não tão eficiente, seria desenvolver

uma espécie de chave metálica que fechasse o circuito quando a peça fosse colocada

na posição em análise. O esquemático desse circuito está na Figura 36. Nele, dois

fios (A e B) foram manipulados em cada superfície de encaixe no tabuleiro e duas

arruelas metálicas foram coladas na base de cada peça a fim de fechar contato com

os dois fios citados.

Nesse circuito, foi utilizado um DEMUX TC4053BP e um MUX 74HCT251 para

mapear as 64 posições do tabuleiro. Um diodo 1N4007 foi colocado em cada posição

para evitar retorno de tensão e um resistor de 330Ω para cada coluna para definir 0V

às colunas não selecionadas pelo MUX naquele momento.

Figura 36 - Representação do circuito de leitura

Para a elaboração do circuito físico, o circuito de leitura foi dividido em 2 sub-

circuitos, um com o MUX e outro com o DEMUX, e elaborados os PCBs apresentados

na Figura 37 e Figura 38 no software Proteus.

Figura 37 - Sub-circuito com DEMUX para o circuito de leitura

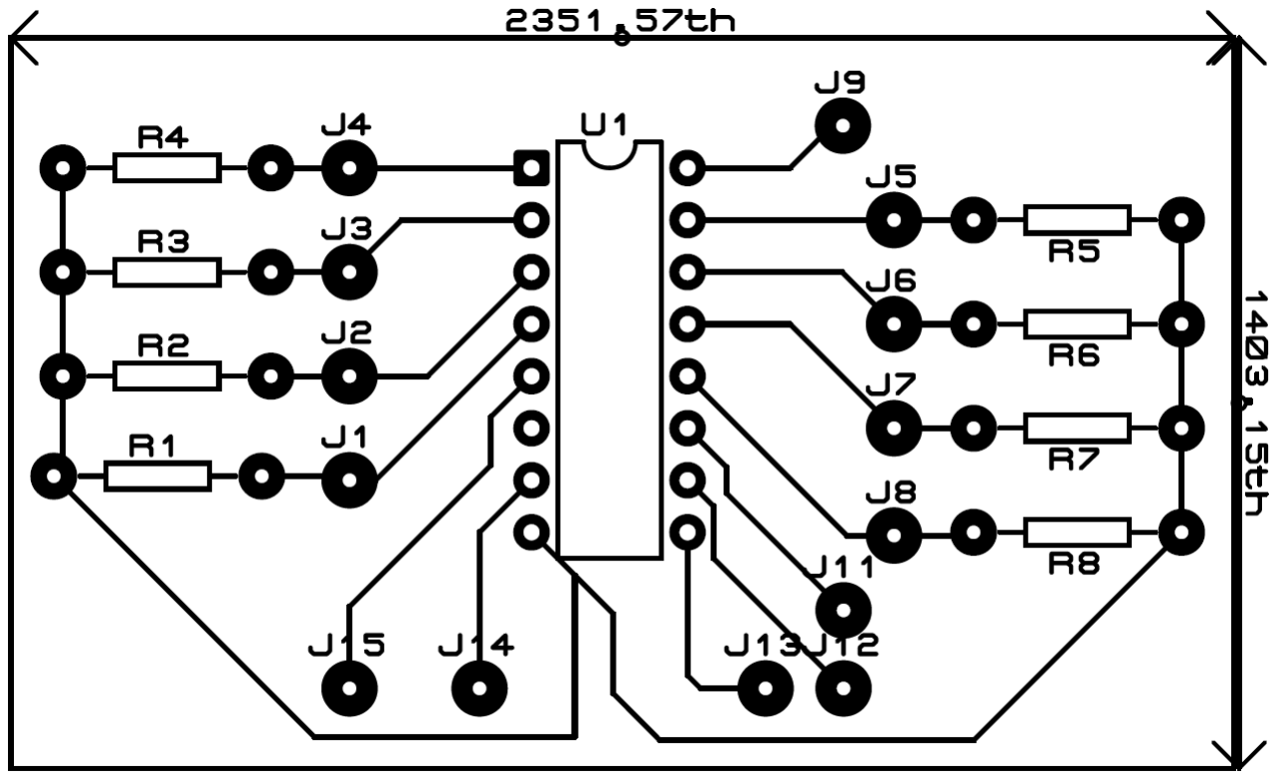
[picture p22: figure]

Figura 38 - Sub-circuito com MUX para o circuito de leitura

A lógica da solução de leitura foi a seguinte: o programa aciona os selects do

DEMUX, que joga 5V na saída selecionada. Cada porta de saída do DEMUX foi

conectada em uma linha do tabuleiro de xadrez, alimentando todas as colunas

daquela linha ao mesmo tempo. O MUX, por sua vez, varia seus selects fechando

contato internamente para a entrada selecionada e abrindo todas as outras 7

entradas. Dessa forma pode ser analisado a tensão na saída do MUX, sendo que, se

houver peça naquela posição, a tensão de saída será 5V, caso contrário os contatos

estarão abertos (não há peça) e a saída será 0V.

### 4.4 Resultados da Montagem Física Completa

A interface porta serial do Arduino se mostrou muito intuitiva para o jogador e

simples de ser utilizada na programação do código. Nela é permitido inserir valores

de linha e coluna para realizar a inserção da posição da peça a ser movida e o destino

dessa mesma peça. Além disso, a interface mostra ao usuário mensagens de erros

caso este tente qualquer jogada inválida.

A solução pensada para o “circuito de escrita” acender mais de um LED ao

mesmo tempo mostrou-se acertada e robusta. O ponto chave para a resolução desse

objetivo foi, através da programação, executar a ação de acender um LED em alta

frequência. Assim, foi possível resolver a limitação do conjunto software/circuito

elétrico e tornar visualmente possível mostrar as posições no tabuleiro “acendendo

mais de um LED por vez”.

O desenvolvimento do protótipo teve início com alguns testes de bancada e

utilizando uma protoboard, ao longo do projeto fez-se necessário a utilização de duas

placas de madeira para representar o tabuleiro de xadrez. Essa solução encontrada

se justifica devido a necessidade de as chaves metálicas ficarem em um nível

diferente dos LEDs. Foi possível realizar furos na placa superior para que os mesmos

abrigassem as peças com arruelas na base para que o contato com as chaves fosse

o mais preciso possível.

Ao utilizar duas placas na parte superior facilitou-se também o corte delas feito

em uma CNC, a fixação dos fios e cabos utilizados para acionamento dos LEDs e da

identificação das peças pelo “circuito de leitura”.

Para a sustentação do tabuleiro, a alocação das ligações (cabos elétricos) e os

circuitos impressos, decidiu-se furar as duas placas superiores (superfície 1 e 2),

utilizar barras roscadas, arruelas e uma base de sustentação. Essa foi uma solução

encontrada para facilitar possíveis alterações ao longo do projeto e uma maneira de

manter organizada todas as ligações.

O resultado da montagem do protótipo, com suas respectivas visões, assim

como um exemplo de peça utilizada, pode ser observado nas figuras a baixo.

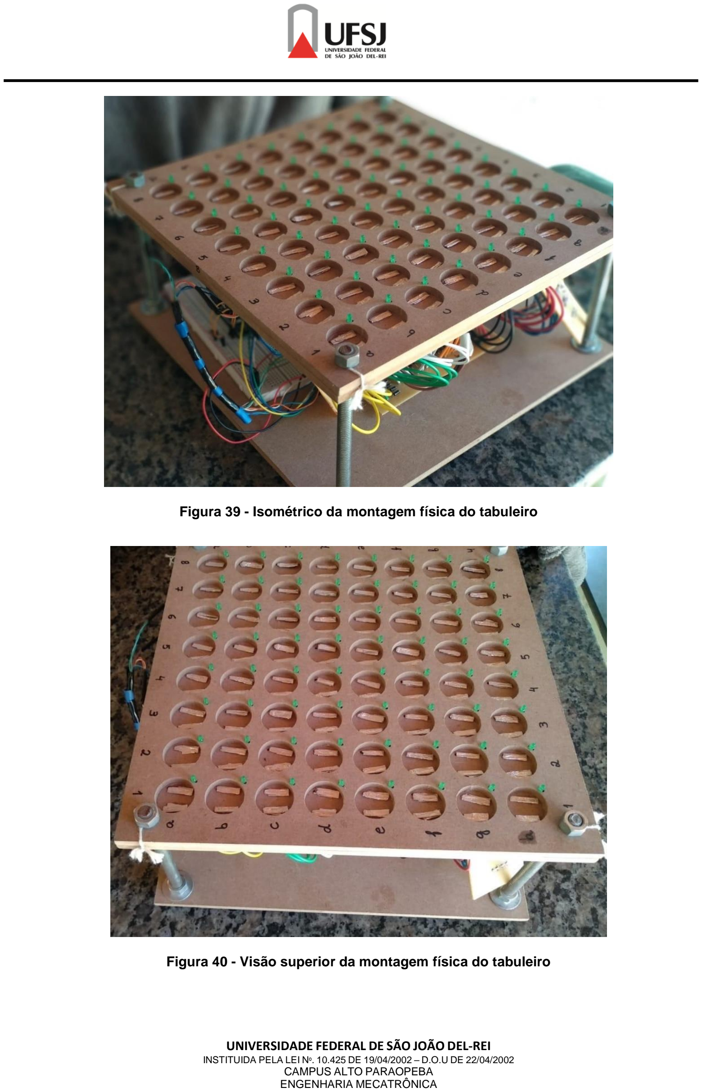
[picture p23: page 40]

Figura 39 - Isométrico da montagem física do tabuleiro

Figura 40 - Visão superior da montagem física do tabuleiro

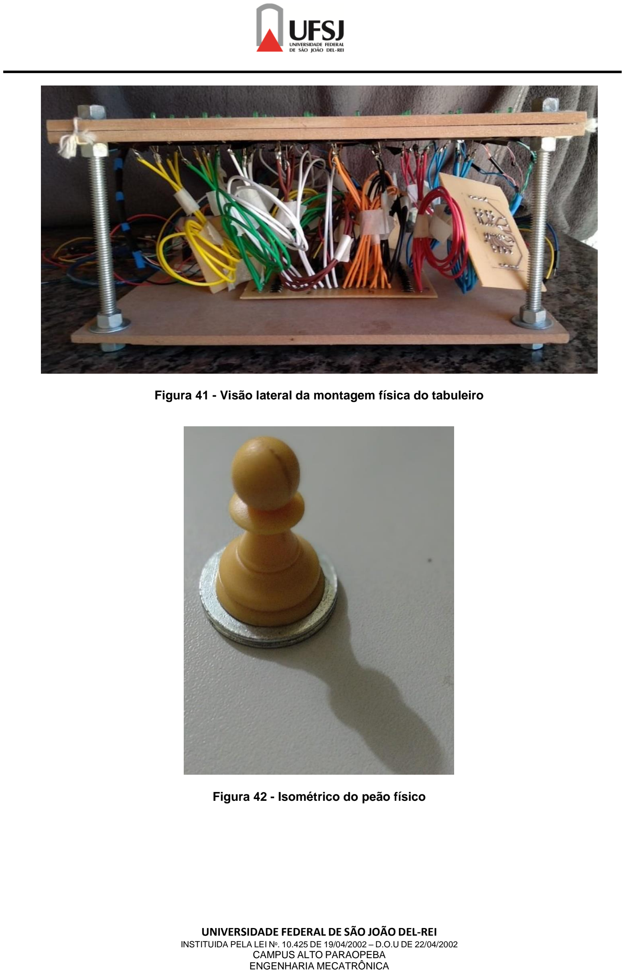
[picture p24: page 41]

Figura 41 - Visão lateral da montagem física do tabuleiro

Figura 42 - Isométrico do peão físico

### 5. CONCLUSÃO

Para realizar a construção de um protótipo com a finalidade pelo qual foi

proposto, é necessário resolver diversos pequenos problemas de hardware e software

que surgem ao longo do projeto. A ponte de união entre essas áreas ocorre com o

auxílio de um microcontrolador.

A integração dessas áreas, utilizando um microcontrolador, para construção do

protótipo é um grande desafio que mostra uma das aplicações, em pequena escala,

de um dos possíveis papéis que o bacharel em ciência e tecnologia pode assumir no

mercado de trabalho.

O protótipo criado funcionou corretamente, dentro de suas limitações de não

ainda não identificar de forma totalmente automática as peças. O maior desafio do

projeto como um todo foi a tentativa de implementação do “circuito de leitura”, que é

uma extensão do projeto, pois a maneira como foi idealizado (utilizando uma chave

metálica) não se mostrou robusto o suficiente para a resolução da proposta para o

qual foi concebido, apesar de ser a solução mais barata encontrada pelo grupo.

Uma das possíveis soluções para esse circuito foi apresentada pelo orientador

do projeto e consistiria em utilizar chaves fim de curso minúsculas, que normalmente

são encontradas em leitores de CD/DVD. Com as características com que são

fabricadas, se fossem substituídos os nossos contatos metálicos implementados por

elas, seria conseguida a robustez necessária para a resolução do problema. A solução

proposta aqui para tal problema não foi implementada devido ao tempo hábil de

apresentação do projeto e dos gastos extras com o mesmo que não estavam viáveis

no momento.

Esse projeto como um todo integrou diversas áreas do conhecimento. O

protótipo construído, acaba sendo uma ótima maneira de introduzir o bacharel em um

universo prático e funcional, agregando assim um grande valor teórico, técnico e

científico.

### 6. REFERÊNCIAS

1. Agência Brasileira de Desenvolvimento Industrial (ABDI). Panorama Setorial de
Eletrônica | para | Automação. | Disponível | em:

<http://www.abdi.com.br/Estudo/eletronica%20para%20automa%C3%A7%C3%A3o.

pdf>. (http://www.abdi.com.br/Estudo/eletronica%20para%20automa%C3%A7%C3%A3o.pdf) Acesso em: 11 de Abril de 2018.

2. | Wikipédia. | Automação. | Disponível | em:

<https://pt.wikipedia.org/wiki/Automa%C3%A7%C3%A3o>. Acesso em: 11 de Abril de

2018.

3. SMIDT, A.C.G. Implementação de uma Plataforma Robótica controlada

remotamente utilizando o Arduíno. São Carlos, 2013. 11 p. Disponível em:

<http://www.tcc.sc.usp.br/tce/disponiveis/97/970010/tce-19112013-

093717/?&lang=br>. Acesso em: 11 de Abril de 2018.

4. OP.CIT. Tradução de Lauand. [S.l.]: [s.n.], 49-51 p.
5. Xadrez Center. O xadrez e a tomada de decisões. Disponível em:

<http://xadrezcentroaweaw.blogspot.com/2011/07/tcc-o-xadrez-e-tomada-de-

decisoes.html>. Acesso em: 11 de Abril de 2018.

6. Confederação Brasileira de Xadrez (CBX). Lei do Xadrez da FIDE. Tradução de
Antonio | Bento. | Revisão | de | Igor | Lutz. | [S.l.]: | [s.n.]. | Disponível | em:

<http://www.cbx.org.br/files/downloads/Xadrez_lei_da_FIDE.pdf>. Acesso em: 11 de

Abril de 2018.

7. Arduino. Download. Disponível em: <https://www.arduino.cc/en/Main/Software>.

Acesso em 09 de Fevereiro de 2018.

8. | Embarcados. | Arduino | Leonardo. | Disponível | em:

<https://www.embarcados.com.br/arduino-leonardo/>. Acesso em: 11 de Abril de

2018.

9. | Dassault | Systemes. | SolidWorks. | Disponível | em:

<https://www.solidworks.com/sw/support/downloads.htm>. Acesso em: 04 de Maio de

2017.

10. | GrabCAD. | Steeline | Chess | Set | Concept. | Disponível | em:

<https://grabcad.com/library/steeline-chess-set-concept-1>. Acesso em: 04 de Maio

de 2017.

11. GitHub. TCIC. Disponível em: <https://github.com/JTOLEDOJ/Tabuleiro-de-

Xadrez-Interativo>. Acesso em: 24 de Junho de 2018.

12. Labcenter. Proteus. Disponível em: <https://www.labcenter.com/downloads/>.

Acesso em: 23 de Agosto de 2017.

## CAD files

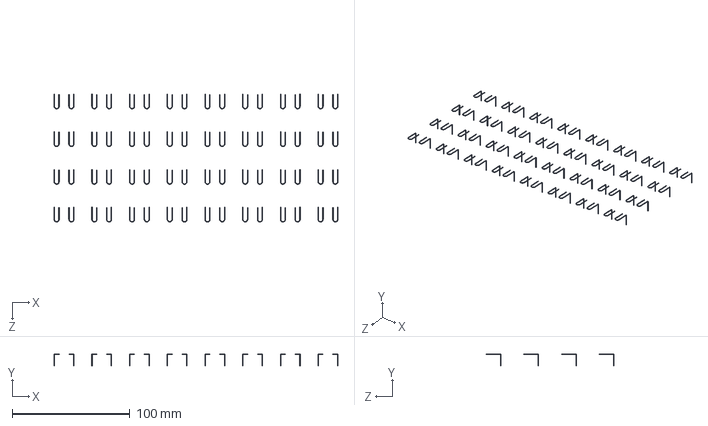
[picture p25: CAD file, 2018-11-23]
Montagem/32_Contatos_Coluna.SLDASM
241.0 x 10.5 x 108.7 mm
Contato_Direito x 32
Contato_Esquerdo x 32

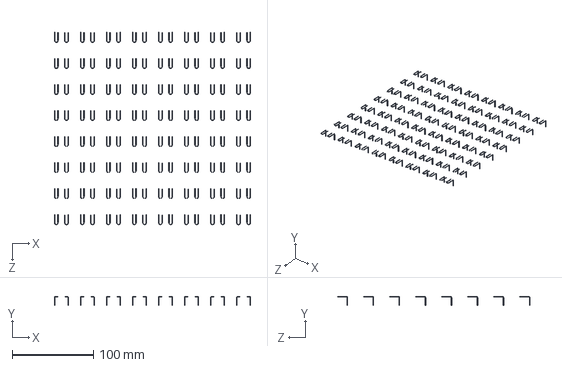
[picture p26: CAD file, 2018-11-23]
Montagem/64_Contatos_Coluna.SLDASM
241.0 x 10.5 x 236.7 mm
Contato_Direito x 64
Contato_Esquerdo x 64

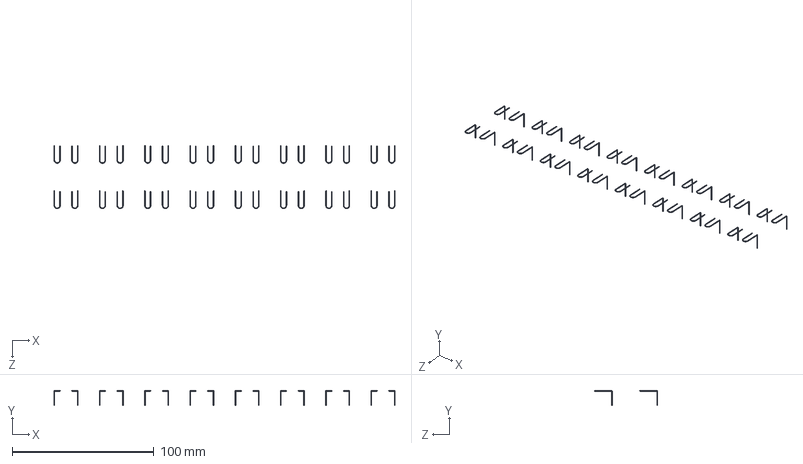
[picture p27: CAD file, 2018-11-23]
Montagem/16_Contatos_Coluna.SLDASM
241.0 x 10.5 x 44.7 mm
Contato_Direito x 16
Contato_Esquerdo x 16

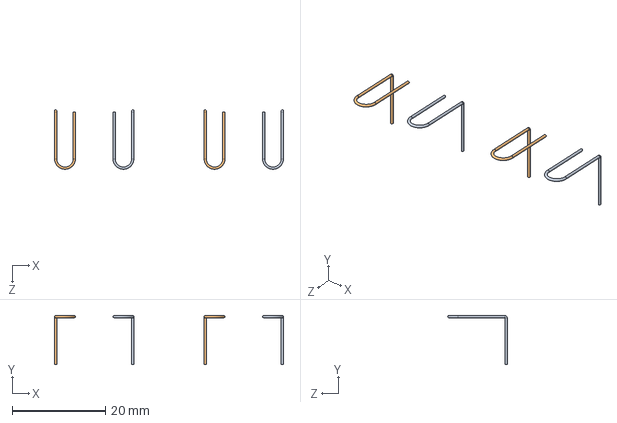
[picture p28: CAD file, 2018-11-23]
Montagem/2_Contatos_Linha.SLDASM
49.0 x 10.5 x 12.7 mm
Contato_Direito x 2
Contato_Esquerdo x 2

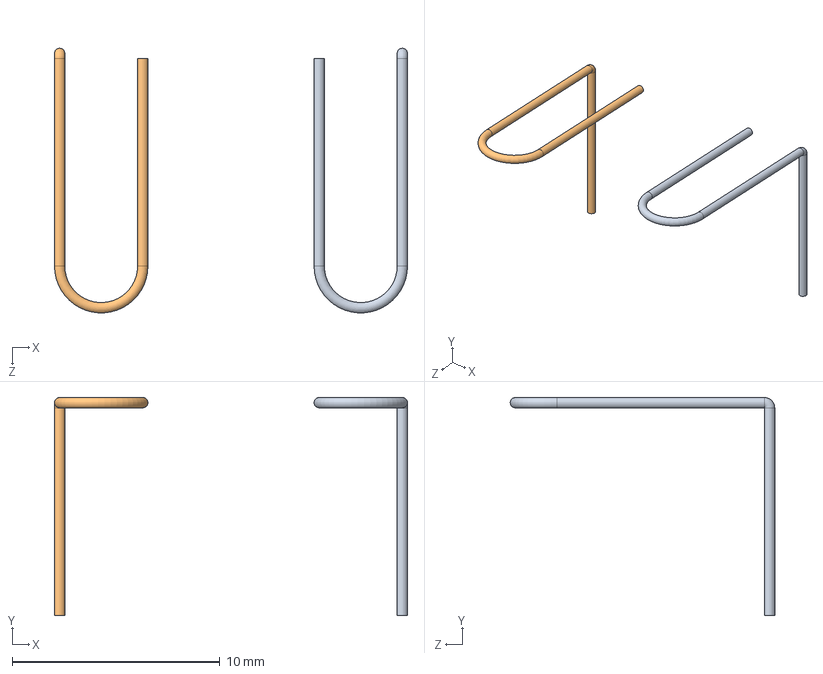
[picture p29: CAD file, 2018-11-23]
Montagem/Contatos_Montagem.SLDASM
17.0 x 10.5 x 12.7 mm
Contato_Direito
Contato_Esquerdo

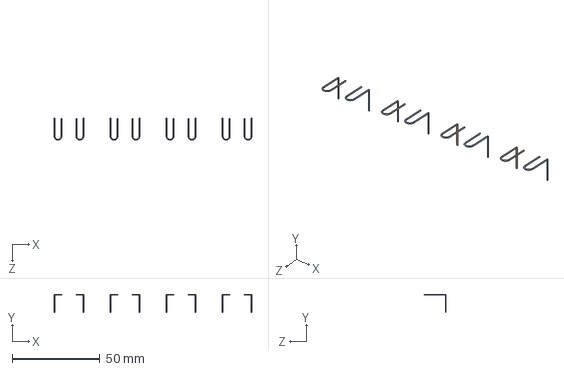
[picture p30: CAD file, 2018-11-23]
Montagem/4_Contatos_Linha.SLDASM
113.0 x 10.5 x 12.7 mm
Contato_Direito x 4
Contato_Esquerdo x 4

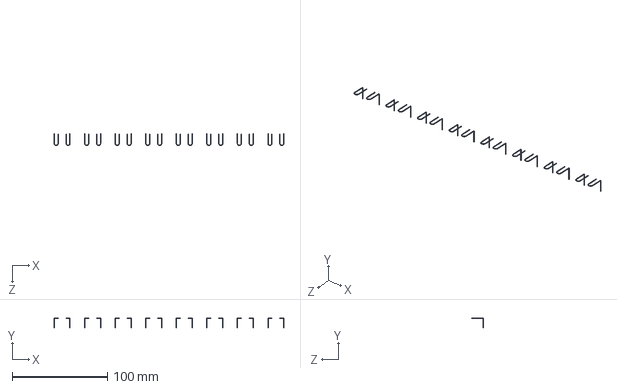
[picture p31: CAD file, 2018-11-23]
Montagem/8_Contatos_Linha.SLDASM
241.0 x 10.5 x 12.7 mm
Contato_Direito x 8
Contato_Esquerdo x 8

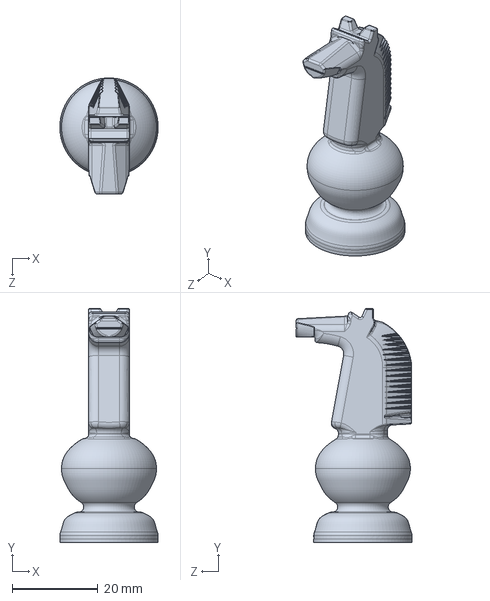
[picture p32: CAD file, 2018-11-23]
Montagem/Cavalo (Branco).SLDPRT
23.0 x 54.7 x 27.2 mm

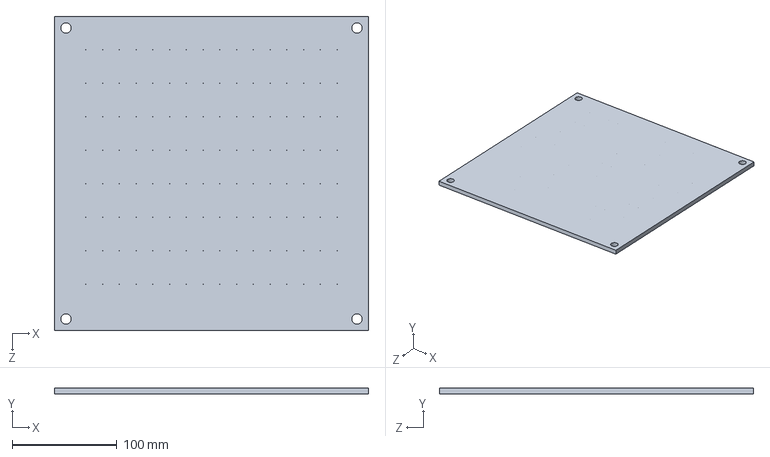
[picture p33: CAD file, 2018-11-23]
Montagem/Superficie2.SLDPRT
300.0 x 6.00 x 300.0 mm

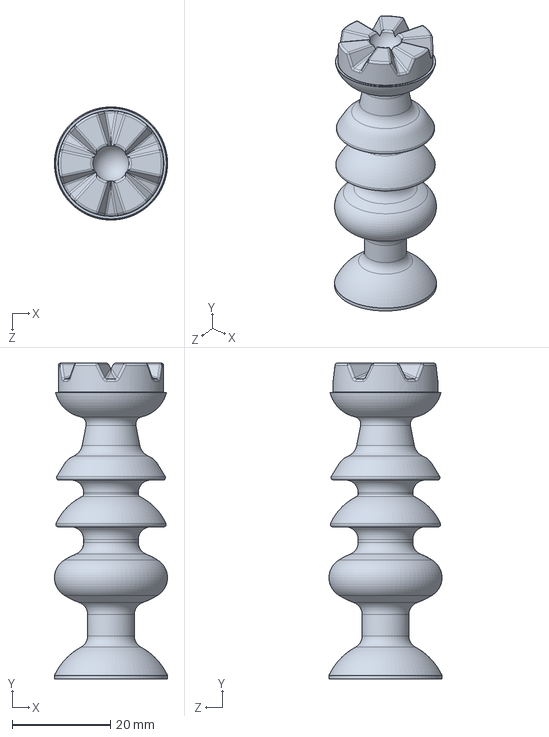
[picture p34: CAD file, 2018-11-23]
Montagem/Rainha (Branco).SLDPRT
23.0 x 64.3 x 23.0 mm

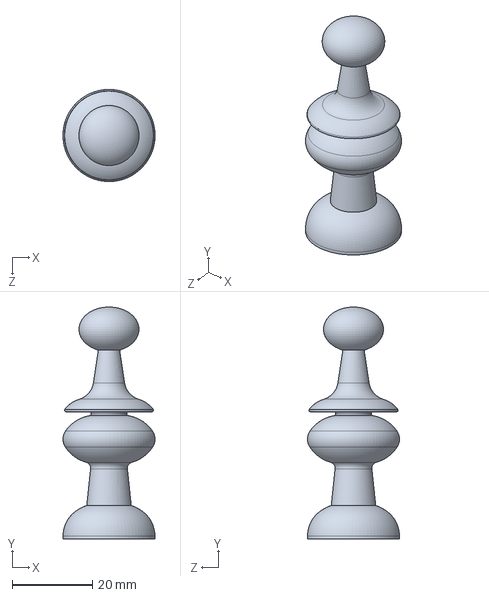
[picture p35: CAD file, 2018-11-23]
Montagem/Bispo (Branco).SLDPRT
23.0 x 57.9 x 23.0 mm

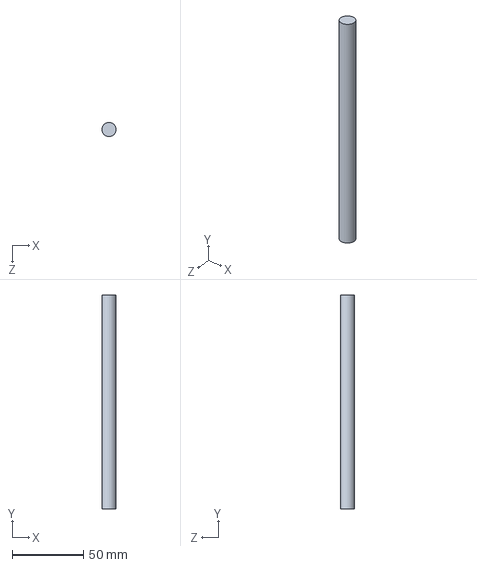
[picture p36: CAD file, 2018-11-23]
Montagem/Barra_Roscada.SLDPRT
10.0 x 150.0 x 10.0 mm

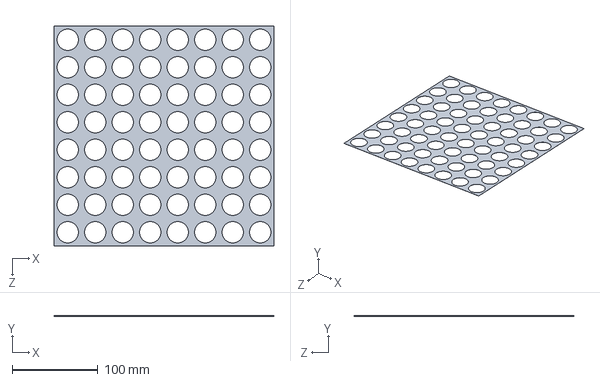
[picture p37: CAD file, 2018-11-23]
Montagem/Papel.SLDPRT
256.0 x 0.1 x 256.0 mm

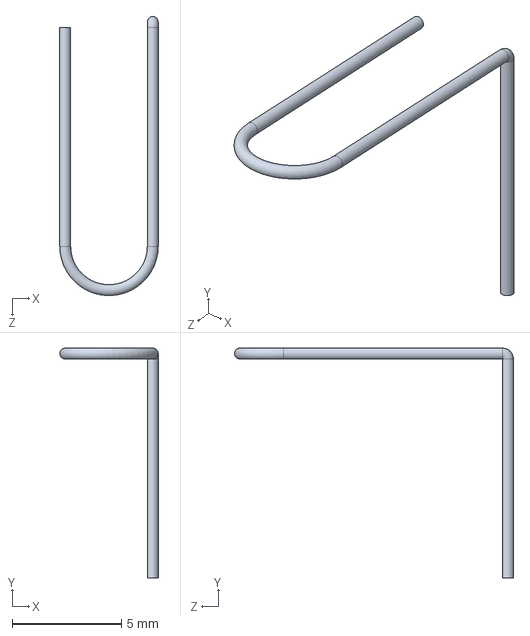
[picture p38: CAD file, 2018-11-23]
Montagem/Contato_Direito.SLDPRT
4.50 x 10.5 x 12.7 mm

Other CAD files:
Montagem/Contato_Esquerdo.SLDPRT
Montagem/Base.SLDPRT
Montagem/Peao (Preto).SLDPRT
Montagem/Peao (Branco).SLDPRT
Montagem/Arruela.SLDPRT
Montagem/Bispo (Preto).SLDPRT
Montagem/Cavalo (Preto).SLDPRT
Montagem/Chapas_Metalicas.SLDPRT
Montagem/LED.SLDPRT
Montagem/Porca.SLDPRT
Montagem/Rainha (Preto).SLDPRT
Montagem/Rei (Branco).SLDPRT
Montagem/Rei (Preto).SLDPRT
Montagem/Superficie1.SLDPRT
Montagem/Torre (Branco).SLDPRT
Montagem/Torre (Preto).SLDPRT

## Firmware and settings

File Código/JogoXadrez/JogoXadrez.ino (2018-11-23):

const int sela = 6;
const int selb = 7;
const int selc = 8;
const int sel1 = 2;
const int sel2 = 3;
const int sel3 = 4;
int campo[8][8];
int linha;
char peca;
int coluna;
bool ok;
bool vezdobranco = true;
bool correto = false;
char linhac = '\0';
char colunac = '\0';
bool certo = false;
// Função que seleciona a linha do circuito de escrita. Recebe um inteiro de 0~7. Não retorna nada.

void SelectDemuxLinha(int s){
  if (s==0){
    digitalWrite(sela,LOW);
    digitalWrite(selb,LOW);
    digitalWrite(selc,LOW);
  }
  else if (s==1){
    digitalWrite(sela,HIGH);
    digitalWrite(selb,LOW);
    digitalWrite(selc,LOW);
  }
  else if (s==2){
    digitalWrite(sela,LOW);
    digitalWrite(selb,HIGH);
    digitalWrite(selc,LOW);
  }
  else if (s==3){
    digitalWrite(sela,HIGH);
    digitalWrite(selb,HIGH);
    digitalWrite(selc,LOW);
  }
  else if (s==4){
    digitalWrite(sela,LOW);
    digitalWrite(selb,LOW);
    digitalWrite(selc,HIGH);
  }
  else if (s==5){
    digitalWrite(sela,HIGH);
    digitalWrite(selb,LOW);
    digitalWrite(selc,HIGH);
  }
  else if (s==6){
    digitalWrite(sela,LOW);
    digitalWrite(selb,HIGH);
    digitalWrite(selc,HIGH);
  }
  else if (s==7){
    digitalWrite(sela,HIGH);
    digitalWrite(selb,HIGH);
    digitalWrite(selc,HIGH);
  }
}

// Função que seleciona a linha do circuito de escrita. Recebe um inteiro de 0~7. Não retorna nada.
void SelectDemuxColuna(int s){
  if (s==0){
    digitalWrite(sel1,LOW);
    digitalWrite(sel2,LOW);
    digitalWrite(sel3,LOW);
  }
  else if (s==1){
    digitalWrite(sel1,HIGH);
    digitalWrite(sel2,LOW);
    digitalWrite(sel3,LOW);
  }
  else if (s==2){
    digitalWrite(sel1,LOW);
    digitalWrite(sel2,HIGH);
    digitalWrite(sel3,LOW);
  }
  else if (s==3){
    digitalWrite(sel1,HIGH);
    digitalWrite(sel2,HIGH);
    digitalWrite(sel3,LOW);
  }
  else if (s==4){
    digitalWrite(sel1,LOW);
    digitalWrite(sel2,LOW);
    digitalWrite(sel3,HIGH);
  }
  else if (s==5){
    digitalWrite(sel1,HIGH);
    digitalWrite(sel2,LOW);
    digitalWrite(sel3,HIGH);
  }
  else if (s==6){
    digitalWrite(sel1,LOW);
    digitalWrite(sel2,HIGH);
    digitalWrite(sel3,HIGH);
  }
  else if (s==7){
    digitalWrite(sel1,HIGH);
    digitalWrite(sel2,HIGH);
    digitalWrite(sel3,HIGH);
  }
}

// Função que acende os Leds. Recebe linha e coluna, setando os demux corretos.
void AcendeLed(int linha, int coluna){
  SelectDemuxLinha(linha);
  SelectDemuxColuna(coluna);
  //Serial.println("ACENDEU");
}

bool Movimenta(){
    
  // Movimentação do peão
  if(abs(campo[linha][coluna]) == 1){
    bool led[4];
    for(int i = 0; i < 4; i++) led[i]=0;
    int linhaaux = linha;
    int colunaaux = coluna;
    if(campo[linha][coluna] == 1){  // Peças brancas
      if(campo[linha+1][coluna] == 0 && campo[linha+2][coluna] == 0 && linha == 1) led[0]=1;
      if((linha+1) < 8){
        if(campo[linha+1][coluna] == 0) led[2]=1;
        if((coluna+1) < 8){
          if(campo[linha+1][coluna+1] < 0) led[3]=1;
        }
        if((coluna-1) >= 0){
          if(campo[linha+1][coluna-1] < 0) led[1]=1;
        }
      }
      //CETADOIDO!!!!!!!!!!!!!!!!!!!!!!!!!!!!
      while (true){
        if(led[0] == 1) AcendeLed(linha+2, coluna);
        delay(10);
        if(led[1] == 1) AcendeLed(linha+1, coluna-1);
        delay(10);
        if(led[2] == 1) AcendeLed(linha+1, coluna);
        delay(10);
        if(led[3] == 1) AcendeLed(linha+1, coluna+1);
        delay(10);
        
        char c = Serial.read();
        
        if(c=='n'){
          break;
        }
        if (c=='y'){
          for (int i = 0; i<4; i++){
            if (led[i]==1) ok = true;
          }
          if (!ok){
            break;
          }
          else{
            Leitura2();
            AcendeLed(linha, coluna);
            if(led[0] == 1 && (linha == linhaaux+2 && coluna == colunaaux)){
              campo[linhaaux][colunaaux] = 0;
              campo[linha][coluna] = 1;
              Serial.println("Movimento Confirmado!");
              certo=true;
              break; 
            }
            if(led[1] == 1 && (linha == linhaaux+1 && coluna == colunaaux-1)){
              campo[linhaaux][colunaaux] = 0;
              campo[linha][coluna] = 1;
              Serial.println("Movimento Confirmado!");
              certo=true;
              break; 
            }
            if(led[2] == 1 && (linha == linhaaux+1 && coluna == colunaaux)){
              campo[linhaaux][colunaaux] = 0;
              campo[linha][coluna] = 1;
              Serial.println("Movimento Confirmado!");
              certo=true;
              break; 
            }
            if(led[3] == 1 && (linha == linhaaux+1 && coluna == colunaaux+1)){
              campo[linhaaux][colunaaux] = 0;
              campo[linha][coluna] = 1;
              Serial.println("Movimento Confirmado!");
              certo=true;
              break; 
            }
            Serial.println("MOVIMENTO ERRADO, TENTE DE NOVO");
            break;
          }
        }
      }
    }
    else{
      if(campo[linha-1][coluna] == 0 && campo[linha-2][coluna] == 0  && linha == 6) led[0]=1;
      if((linha-1) >= 0){
        if(campo[linha-1][coluna] == 0) led[2]=1;
        if((coluna-1) >= 0){
          if(campo[linha-1][coluna-1] > 0) led[3]=1;
        }
        if((coluna+1) < 8){
          if(campo[linha-1][coluna+1] > 0) led[1]=1;
        }
      }
      while (true){
        if(led[0] == 1) AcendeLed(linha-2, coluna);
        delay(10);
        if(led[1] == 1) AcendeLed(linha-1, coluna+1);
        delay(10);
        if(led[2] == 1) AcendeLed(linha-1, coluna);
        delay(10);
        if(led[3] == 1) AcendeLed(linha-1, coluna-1);
        delay(10);
        char c = Serial.read();
        if(c=='n'){
          break;
        }
        if (c=='y'){
          for (int i = 0; i<4; i++){
            if (led[i]==1) ok = true;
          }
          if (!ok){
            break;
          }
          else{
            Leitura2();
            AcendeLed(linha, coluna);
            if(led[0] == 1 && (linha == linhaaux-2 && coluna == colunaaux)){
              campo[linhaaux][colunaaux] = 0;
              campo[linha][coluna] = -1;
              Serial.println("Movimento Confirmado!");
              certo=true;
              break; 
            }
            if(led[1] == 1 && (linha == linhaaux-1 && coluna == colunaaux+1)){
              campo[linhaaux][colunaaux] = 0;
              campo[linha][coluna] = -1;
              Serial.println("Movimento Confirmado!");
              certo=true;
              break; 
            }
            if(led[2] == 1 && (linha == linhaaux-1 && coluna == colunaaux)){
              campo[linhaaux][colunaaux] = 0;
              campo[linha][coluna] = -1;
              Serial.println("Movimento Confirmado!");
              certo=true;
              break; 
            }
            if(led[3] == 1 && (linha == linhaaux-1 && coluna == colunaaux-1)){
              campo[linhaaux][colunaaux] = 0;
              campo[linha][coluna] = -1;
              Serial.println("Movimento Confirmado!");
              certo=true;
              break; 
            }
            Serial.println("MOVIMENTO ERRADO, TENTE DE NOVO");
            break;
          }
        }
      
     }
    }
  }

  // Movimentação da torre
  else if(abs(campo[linha][coluna]) == 2){
      bool achou = false;
      int l=0, r=0, u=0, d=0;
      
      for(int i = 1; (linha-i) >= 0; i++){
        if (campo[linha-i][coluna] != 0){
          d = i;
          achou = true;
        }
        if(achou) break;
        else d=i;
      }
      achou = false;
      
      for(int i = 1; (linha+i) <= 7; i++){
        if (campo[linha+i][coluna] != 0){
          u = i;
          achou = true;
        }
        if(achou) break;
        else u=i;
      }
      achou = false;
     
      for(int i = 1; (coluna + i) <= 7; i++){
        if (campo[linha][coluna+i] != 0){
          r = i;
          achou = true;
        }
        if(achou) break;
        else r=i;
      }
      achou = false;
      
      for(int i = 1; (coluna-i) >= 0; i++){
        if (campo[linha][coluna-i] != 0){
          l = i;
          achou = true;
        }
        if(achou) break;
        else l=i;
      }
      achou = false;
      while(true){
        for(int i = 1; i < d ; i++){
          if(linha-i > 0) AcendeLed(linha-i, coluna);
          delay(5);
        }
        if(campo[linha][coluna]*campo[linha-d][coluna] <= 0) AcendeLed(linha-d, coluna);
        delay(5);
        
        for(int i = 1; i < u; i++){
          if(linha+i < 7) AcendeLed(linha+i, coluna);
          delay(5);
        }
        if (campo[linha][coluna]*campo[linha+u][coluna] <= 0) AcendeLed(linha+u, coluna);
        delay(5);
        
        for(int i = 1; i < l; i++){
          if(coluna-i > 0) AcendeLed(linha, coluna-i);
          delay(5);
        }
        if(campo[linha][coluna]*campo[linha][coluna-l] <= 0) AcendeLed(linha, coluna-l);
        delay(5);
        
        for(int i = 1; i < r; i++){
          if(coluna + i < 7 ) AcendeLed(linha, coluna+i);
          delay(5);
        }
        if(campo[linha][coluna]*campo[linha][coluna+r] <= 0) AcendeLed(linha, coluna+r);
        delay(5);
        char c = Serial.read();
        if(c=='n'){
          break;
        }
        if (c=='y'){
          if (u == 0 && l == 0 && r == 0 && d ==0){
            break;
          }
          else{
            int linhaaux = linha;
            int colunaaux = coluna;
            Leitura2();
            AcendeLed(linha, coluna);
            if(linha<=linhaaux+u && coluna == colunaaux && linha >= linhaaux-d){
              if ((campo[linhaaux][colunaaux])*(campo[linha][coluna])<=0){
                
                campo[linhaaux][colunaaux] = 0;
                if (vezdobranco) campo[linha][coluna] = 2;
                if (!vezdobranco) campo[linha][coluna] = -2;
                Serial.println("Movimento Confirmado!");
                certo=true;
                break;
              } 
            }
            if(linha == linhaaux && coluna <= colunaaux+r && coluna >= coluna-l){
              if ((campo[linhaaux][colunaaux])*(campo[linha][coluna])<=0){
                campo[linhaaux][colunaaux] = 0;
                if (vezdobranco) campo[linha][coluna] = 2;
                if (!vezdobranco) campo[linha][coluna] = -2;
                Serial.println("Movimento Confirmado!");
                certo=true;
                break;
              } 
            }
            Serial.println("MOVIMENTO ERRADO, TENTE DE NOVO");
            break;
          }
        }
      }
    }
  
  // Movimentação do cavalo
  else if(abs(campo[linha][coluna]) == 3){
    bool led[8];
    for(int i = 0; i < 8; i++) led[i]=0;
    
    if((linha+2) < 8){
      if((coluna+1) < 8){
        if(campo[linha+2][coluna+1] != 0){
          if(campo[linha][coluna]*campo[linha+2][coluna+1] < 0) led[0]=1;
        }
        else led[0]=1;
      }
      
      if((coluna-1) >= 0){
        if(campo[linha+2][coluna-1] != 0){
          if(campo[linha][coluna]*campo[linha+2][coluna-1] < 0) led[1]=1;
        }
        else led[1]=1;
      }
    }
    
    if((linha-2) >= 0){
      if((coluna+1) < 8){
        if(campo[linha-2][coluna+1] != 0){
          if(campo[linha][coluna]*campo[linha-2][coluna+1] < 0) led[2]=1;
        }
        else led[2]=1;
      }
      
      if((coluna-1) >= 0){
        if(campo[linha-2][coluna-1] != 0){
          if(campo[linha][coluna]*campo[linha-2][coluna-1] < 0) led[3]=1;
        }
        else led[3]=1;
       }
    }
     
    if((coluna+2) < 8){
      if((linha+1) < 8){
        if(campo[linha+1][coluna+2] != 0){
          if(campo[linha][coluna]*campo[linha+1][coluna+2] < 0) led[4]=1;
        }
        else led[4]=1;
      }
      if((linha-1) > 0){
        if(campo[linha-1][coluna+2] != 0){
          if(campo[linha][coluna]*campo[linha-1][coluna+2] < 0) led[5]=1;
        }
        else led[5]=1;
      }
    }
    
    if((coluna-2) >= 0){
      if((linha+1) < 8){
        if(campo[linha+1][coluna-2] != 0){
          if(campo[linha][coluna]*campo[linha+1][coluna-2] < 0) led[6]=1;
        }
        else led[6]=1;
      }
      if((linha-1) > 0){
        if(campo[linha-1][coluna-2] != 0){
          if(campo[linha][coluna]*campo[linha-1][coluna-2] < 0) led[7]=1;
        }
        else led[7]=1;     
      }
    }
  
    while (true){
      if(led[0] == 1) AcendeLed(linha+2, coluna+1);
      delay(5);
      if(led[1] == 1) AcendeLed(linha+2, coluna-1);
      delay(5);
      if(led[2] == 1) AcendeLed(linha-2, coluna+1);
      delay(5);
      if(led[3] == 1) AcendeLed(linha-2, coluna-1);
      delay(5);
      if(led[4] == 1) AcendeLed(linha+1, coluna+2);
      delay(5);
      if(led[5] == 1) AcendeLed(linha-1, coluna+2);
      delay(5);
      if(led[6] == 1) AcendeLed(linha+1, coluna-2);
      delay(5);
      if(led[7] == 1) AcendeLed(linha-1, coluna-2);
      delay(5);
      
      char c = Serial.read();
      if(c=='n'){
          break;
        }
      if(c== 'y'){
        int colunaaux = coluna;
        int linhaaux = linha;
        Leitura2();
        AcendeLed(linha, coluna);
        if(led[0] == 1 && linha == linhaaux+2 && coluna == colunaaux+1){
          campo[linhaaux][colunaaux]=0;
          if(vezdobranco) campo[linha][coluna]=3;
          if(!vezdobranco) campo[linha][coluna]=-3;
          Serial.println("Movimento Confirmado!");
          certo=true;
          break;
        }
        if(led[1] == 1 && linha == linhaaux+2 && coluna == colunaaux-1){
          campo[linhaaux][colunaaux]=0;
          if(vezdobranco) campo[linha][coluna]=3;
          if(!vezdobranco) campo[linha][coluna]=-3;
          Serial.println("Movimento Confirmado!");
          certo=true;
          break;
        }
        if(led[2] == 1 && linha == linhaaux-2 && coluna == colunaaux+1){
          campo[linhaaux][colunaaux]=0;
          if(vezdobranco) campo[linha][coluna]=3;
          if(!vezdobranco) campo[linha][coluna]=-3;
          Serial.println("Movimento Confirmado!");
          certo=true;
          break;
        }
        if(led[3] == 1 && linha == linhaaux-2 && coluna == colunaaux-1){
          campo[linhaaux][colunaaux]=0;
          if(vezdobranco) campo[linha][coluna]=3;
          if(!vezdobranco) campo[linha][coluna]=-3;
          Serial.println("Movimento Confirmado!");
          certo=true;
          break;
        }
        if(led[4] == 1 && linha == linhaaux+1 && coluna == colunaaux+2){
          campo[linhaaux][colunaaux]=0;
          if(vezdobranco) campo[linha][coluna]=3;
          if(!vezdobranco) campo[linha][coluna]=-3;
          Serial.println("Movimento Confirmado!");
          certo=true;
          break;
        }
        if(led[5] == 1 && linha == linhaaux-1 && coluna == colunaaux+2){
          campo[linhaaux][colunaaux]=0;
          if(vezdobranco) campo[linha][coluna]=3;
          if(!vezdobranco) campo[linha][coluna]=-3;
          Serial.println("Movimento Confirmado!");
          certo=true;
          break;
        }
        if(led[6] == 1 && linha == linhaaux+1 && coluna == colunaaux-2){
          campo[linhaaux][colunaaux]=0;
          if(vezdobranco) campo[linha][coluna]=3;
          if(!vezdobranco) campo[linha][coluna]=-3;
          Serial.println("Movimento Confirmado!");
          certo=true;
          break;
        }
        if(led[7] == 1 && linha == linhaaux-1 && coluna == colunaaux-2){
          campo[linhaaux][colunaaux]=0;
          if(vezdobranco) campo[linha][coluna]=3;
          if(!vezdobranco) campo[linha][coluna]=-3;
          Serial.println("Movimento Confirmado!");
          certo=true;
          break;
        }
        Serial.println("MOVIMENTO ERRADO, TENTE DE NOVO");
        break;
      }
    }
  }

  // Movimentação do bispo
  else if(abs(campo[linha][coluna]) == 4){
    bool achou = false;
    int ld=0, lu=0, rd=0, ru=0;
    
    for(int i = 1; (linha-i >= 0 && coluna-i >= 0); i++){
      if(campo[linha-i][coluna-i] != 0){
        ld = i;
        achou = true;
      }
      if(achou) break;
      else ld=i;
    }
    achou = false;
    
    for(int i = 1; (linha+i <= 7 && coluna-i >= 0); i++){
      if(campo[linha+i][coluna-i] != 0){
        lu = i;
        achou = true;
      }
      if (achou) break;
      else lu=i;
    }
    achou = false;
    
    for(int i = 1; (linha+i <= 7 && coluna+i <= 7); i++){
      if(campo[linha+i][coluna+i] != 0){
        ru = i;
        achou = true;
      }
      if (achou) break;
      else ru=i;
    }
    achou = false;
    for (int i = 1; (linha-i >= 0 && coluna+i <= 7); i++){
      if (campo[linha-i][coluna+i] != 0){
        rd = i;
        achou = true;
      }
      if (achou) break;
      else rd=i;
    }
    achou = false;
    
    while(true){
      //Serial.println(lu);
      //Serial.println(ld);
      //Serial.println(ru);
      //Serial.println(rd);
      for(int i = 1; i < lu ; i++){
        if (linha+i < 8 && coluna-i >= 0) AcendeLed(linha+i, coluna-i);
        delay(5);
        //Serial.println("Acende, porra!");
      }
      if(campo[linha][coluna]*campo[linha-lu][coluna+lu] <= 0) AcendeLed(linha + lu, coluna - lu);
      delay(5);
      
      for(int i = 1; i < ru; i++){
        if(linha + i < 8 && coluna + i < 8 ) AcendeLed(linha + i, coluna + i);
        delay(5);
      }
      if(campo[linha][coluna]*campo[linha+ru][coluna+ru] <= 0) AcendeLed(linha + ru, coluna + ru);
      delay(5);
      
      for(int i = 1; i < ld; i++){
        if(linha-i >= 0 && coluna-i >= 0 ) AcendeLed(linha-i, coluna-i);
        delay(5);

      }
      if(campo[linha][coluna]*campo[linha-ld][coluna-ld] <= 0) AcendeLed(linha-ld, coluna-ld);
      delay(5);
      for(int i = 1; i < rd; i++){
        if(linha - i >= 0 && coluna + i < 8 ) AcendeLed(linha - i, coluna + i);
        delay(5);
      }
      if(campo[linha][coluna]*campo[linha-rd][coluna+rd] <= 0) AcendeLed(linha - rd, coluna + rd);
      delay(5);
      char c = Serial.read();
      if(c=='n'){
          break;
      }
      if (c=='y'){
        
          if (rd == 0 && ld == 0 && ru == 0 && lu ==0){
            break;
          }
          else{
            int linhaaux = linha;
            int colunaaux = coluna;
            Leitura2();
            AcendeLed(linha, coluna);
            int teste1 = abs(linhaaux-linha);
            int teste2 = abs(colunaaux-coluna);
            
            while (teste1!=teste2){
              Leitura2();
              AcendeLed(linha, coluna);
              teste1 = abs(linhaaux-linha);
              teste2 = abs(colunaaux-coluna);  
            }
            
            if(linha<=linhaaux+ru && coluna<=colunaaux+ru && linha >= linhaaux-ld && coluna >= colunaaux-ld){
              if ((campo[linhaaux][colunaaux])*(campo[linha][coluna])<=0){
                campo[linhaaux][colunaaux] = 0;
                if (vezdobranco) campo[linha][coluna] = 4;
                if (!vezdobranco) campo[linha][coluna] = -4;
                Serial.println("Movimento Confirmado!");
                certo=true;
                break;
              } 
            }
            if(linha >= linhaaux-rd && coluna <= colunaaux+rd && linha <= linhaaux+lu && coluna >= colunaaux-lu){
              if ((campo[linhaaux][colunaaux])*(campo[linha][coluna])<=0){
                campo[linhaaux][colunaaux] = 0;
                if (vezdobranco) campo[linha][coluna] = 4;
                if (!vezdobranco) campo[linha][coluna] = -4;
                Serial.println("Movimento Confirmado!");
                certo=true;
                break;
              } 
            }
         
            Serial.println("MOVIMENTO ERRADO, TENTE DE NOVO");
            break;
            }
       }
     }
   }

  // Movimentação da rainha
  else if(abs(campo[linha][coluna]) == 5){
    bool achou = false;
    int ld=0, lu=0, rd=0, ru=0, l=0, r=0, u=0, d=0;
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
void loop(){
  bool achou = false;
  if(vezdobranco) Serial.println("Vez do Branco");
  else Serial.println("Vez do Preto");
  
  Leitura();
  while(!achou){
    achou = true;
    while(campo[linha][coluna] == 0){
      Serial.println("Peça não encontrada! Verifique linha e coluna!");
      Leitura();
      achou = false;
    }
    while(vezdobranco && campo[linha][coluna] < 0){
      Serial.println("Opa, peça do adversário. Tente de novo");
      Leitura();
      achou = false;
    }
    while(!vezdobranco && campo[linha][coluna] > 0){
      Serial.println("Opa, peça do adversário. Tente de novo");
      Leitura();
      achou = false;
    }
  }
  if(achou){
    if (abs(campo[linha][coluna])==1) Serial.println("Peao"); 
    if (abs(campo[linha][coluna])==2) Serial.println("Torre"); 
    if (abs(campo[linha][coluna])==3) Serial.println("Cavalo"); 
    if (abs(campo[linha][coluna])==4) Serial.println("Bispo"); 
    if (abs(campo[linha][coluna])==5) Serial.println("Rainha"); 
    if (abs(campo[linha][coluna])==6) Serial.println("Rei"); 
    Serial.println("Digite y para confirmar o movimento e n para mexer outra peça");
    Movimenta();
  }

  if(certo){
  if(vezdobranco) vezdobranco = false;
  else vezdobranco = true;
  certo=false;
  }
}

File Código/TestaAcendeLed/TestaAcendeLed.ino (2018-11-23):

const int sel1= 6;
const int sel2= 7;
const int sel3= 8;
const int l1 = 2;
const int l2 = 3;
const int l3 = 4;

void select(int s){
  if (s==0){
    digitalWrite(sel1,LOW);
    digitalWrite(sel2,LOW);
    digitalWrite(sel3,LOW);
    
  }
  else if (s==1){
    digitalWrite(sel1,HIGH);
    digitalWrite(sel2,LOW);
    digitalWrite(sel3,LOW);
  }
  else if (s==2){
    digitalWrite(sel1,LOW);
    digitalWrite(sel2,HIGH);
    digitalWrite(sel3,LOW);
  }
  else if (s==3){
    digitalWrite(sel1,HIGH);
    digitalWrite(sel2,HIGH);
    digitalWrite(sel3,LOW);
  }
  else if (s==4){
    digitalWrite(sel1,LOW);
    digitalWrite(sel2,LOW);
    digitalWrite(sel3,HIGH);
  }
  else if (s==5){
    digitalWrite(sel1,HIGH);
    digitalWrite(sel2,LOW);
    digitalWrite(sel3,HIGH);
  }
  else if (s==6){
    digitalWrite(sel1,LOW);
    digitalWrite(sel2,HIGH);
    digitalWrite(sel3,HIGH);
  }
  else if (s==7){
    digitalWrite(sel1,HIGH);
    digitalWrite(sel2,HIGH);
    digitalWrite(sel3,HIGH);
  }
}

void select2(int s){
  if (s==0){
    digitalWrite(l1,LOW);
    digitalWrite(l2,LOW);
    digitalWrite(l3,LOW);
  }
  else if (s==1){
    digitalWrite(l1,HIGH);
    digitalWrite(l2,LOW);
    digitalWrite(l3,LOW);
  }
  else if (s==2){
    digitalWrite(l1,LOW);
    digitalWrite(l2,HIGH);
    digitalWrite(l3,LOW);
  }
  else if (s==3){
    digitalWrite(l1,HIGH);
    digitalWrite(l2,HIGH);
    digitalWrite(l3,LOW);
  }
  else if (s==4){
    digitalWrite(l1,LOW);
    digitalWrite(l2,LOW);
    digitalWrite(l3,HIGH);
  }
  else if (s==5){
    digitalWrite(l1,HIGH);
    digitalWrite(l2,LOW);
    digitalWrite(l3,HIGH);
  }
  else if (s==6){
    digitalWrite(l1,LOW);
    digitalWrite(l2,HIGH);
    digitalWrite(l3,HIGH);
  }
  else if (s==7){
    digitalWrite(l1,HIGH);
    digitalWrite(l2,HIGH);
    digitalWrite(l3,HIGH);
  }
}

  
void setup(){
  pinMode(sel1, OUTPUT);
  pinMode(sel2, OUTPUT);
  pinMode(sel3, OUTPUT);
  pinMode(l1, OUTPUT);
  pinMode(l2, OUTPUT);
  pinMode(l3, OUTPUT);    
}

void loop(){
  for(int i=0; i<8; i++){
    select(i);
    for(int j=0; j<8; j++){
     select2(j);
     delay(50);
    }
  }
}
